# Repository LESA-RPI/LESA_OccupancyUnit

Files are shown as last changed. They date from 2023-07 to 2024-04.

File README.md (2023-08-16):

# LESA_OccupancyUnit (BLE_MeshLightingPRFNode)
## Tutorials
https://drive.google.com/drive/folders/18Ncf5kQ7dq59xiIikijq2Gq61cseJHMG?usp=sharing

## Table of Contents
- [Folder Navigation](#folder-navigation)
- [Flow charts](#flow-charts)
- [How to use](#how-to-use)
- [How it works](#how-it-works)
- [How it runs](#how-it-runs)
- [Bluetooth setting](#bluetooth-setting)
- [Tracking Algorithm](#tracking-algorithm)
- [Sensor related files](#sensor-related-files)
- [Summer Team Contact Information](#summer-team-contact-information)

## Folder Navigation
1. [NON-STM32 Project Folder](https://github.com/IAmiku/LESA_OccupancyUnit/tree/main/NON-STM32%20Project%20Folder)
    - [App](https://github.com/IAmiku/LESA_OccupancyUnit/tree/main/NON-STM32%20Project%20Folder/App)
    - [DataBase](https://github.com/IAmiku/LESA_OccupancyUnit/tree/main/NON-STM32%20Project%20Folder/DataBase)
    - [ESP-TCS3430](https://github.com/IAmiku/LESA_OccupancyUnit/tree/main/NON-STM32%20Project%20Folder/ESP-TCS3430)
    - [ESP-TMD3725/readreg](https://github.com/IAmiku/LESA_OccupancyUnit/tree/main/NON-STM32%20Project%20Folder/ESP-TMD3725/readreg)
    - [ESPreceverArduino](https://github.com/IAmiku/LESA_OccupancyUnit/tree/main/NON-STM32%20Project%20Folder/ESPreceverArduino)
2. [STM32CubeIDE](https://github.com/IAmiku/LESA_OccupancyUnit/tree/main/STM32CubeIDE)

Based on STM's *BLE_MeshLightingPRFNode* example, this project gets data from the ToF and color sensor. Bluetooth functionality has not been fully developed

## Flow charts

### Current Program Overview (STM32 occupancy detection)
```mermaid
graph TD
boot(Initilizaiton of STM32 and task registrations) ---> init(Sensor Init) --wait for init to finish--> standby{Standby};
subgraph Appli_mesh.c & others
standby --sw1 short press--> reply1(BLE color value advertisement);
reply1-->standby
standby --sw1 long press--> reply2(BLE ToF value advertisement);
reply2---> standby
standby --sw2 long press--> base(background set up)---> standby
standby -->change{Color INT}-->sensor(wakes up ToF and data pulling)--No blobs present for long period-->standby
standby --sw2 short press--> loopyloop1(ToF matrix to UART)
loopyloop1--sw2 short press--> standby
end
```

### Project Overview 
```mermaid
graph LR
subgraph Room
unit1[Server];unit2[Server];unit3[Server];unit4[Server];unit5{Client};
unit1 & unit2 ---- unit3 & unit4
unit5 ---- unit1
end
unit5 ---- building[Building management sys]
```
Server and Clients are defined by
```
#define ENABLE_SENSOR_MODEL_SERVER                                           (1)
#define ENABLE_SENSOR_MODEL_CLIENT                                           (0)
```
, where server is the one with sensor running, and client is the one requesting or listening

### Conituous ToF matrix pulling configuration
```mermaid
graph TD

server[Server]
esp[EPS32]
server <--HTTP--> esp
subgraph Module
stm[STM32] <--UART--> esp
stm <--I2C--> colorsensor[ColorS]
stm <--I2C--> tof[ToF]
end
```

## Wiring Diagram
<p align="center">
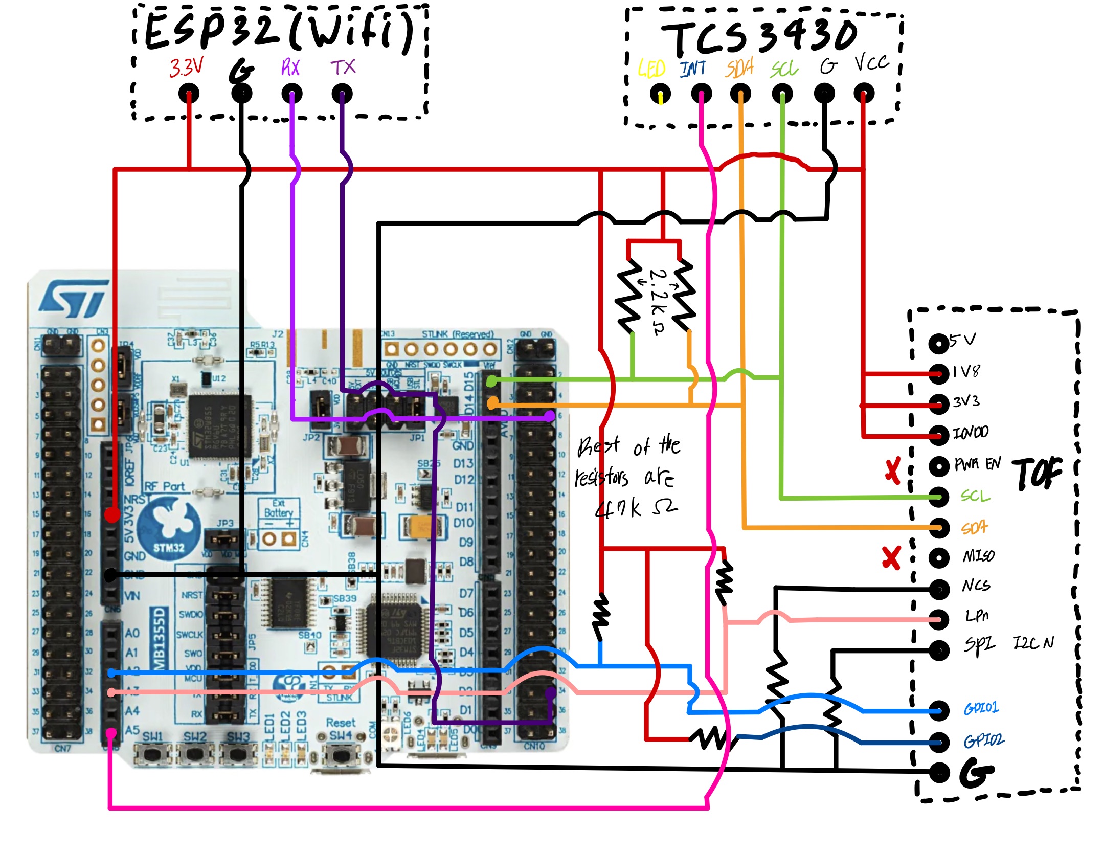
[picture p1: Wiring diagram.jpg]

</p>
Some of external resistors are necessary as the diagram above shown since the L8 TOF board does not internal resistors on it.

## How to use
In order to use this project you must download this entire repository and open the `.project` file in the STM32CubeIDE folder:

|  |  |
|--|--|
| This is how the files should be placed in the workspace folder | Open the project by clicking the .project file |

## How it works

### How it runs

The example software provided by ST uses a sequencer library for scheduling tasks. 

Before using the sequencer it must be initialized by a call to the function :

`UTIL_SEQ_Init( void )`

A function is registered as a task in the sequencer by

`UTIL_SEQ_RegTask( UTIL_SEQ_bm_t TaskId_bm, uint32_t Flags, void (*Task)( void ) )`

The first parameter is the task ID and is a 32-bit value where only one bit should be set, i.e. 
the maximum number of tasks is 32. The second parameter is not used for anything by the library, and the third parameter is a pointer to the function which should be called when it is time for the task to run.

To request a task to be runned, use function 

`UTIL_SEQ_SetTask( UTIL_SEQ_bm_t TaskId_bm , uint32_t Task_Prio )`

Example:
```
UTIL_SEQ_Init( void )
UTIL_SEQ_RegTask((1 << 4), UTIL_SEQ_RFU, my_task_function);
UTIL_SEQ_SetTask((1 << 4), CFG_SEQ_Prio_0);
```

### Bluetooth setting

This project envisioned using BLE mesh to communicate between units. Click [here](Doc/readme.txt) to learn more.

## Tracking Algorithm

[`Tracking_Algo.h`](Core/Inc/Tracking_Algo.h) Function declerations and Macro settings for STM32

[`Tracking_Algo.c`](Core/Src/Tracking_Algo.c) Algorithm itself, can be copied into an online C compiler to run and test

##### TODO: 
- update `void link_latest_frame_to_previous(FIFObuffer *fifobuffer)` to allow multi-frame traceback 
- update `void int find_centers_of_mass(int matrix[N][N], Point *center_of_mass)` in `FrameInfo parse_frame(int matrix[N][N], float deltaX, float deltaY)` to allow track person better

## Sensor related files

##### VL53L8CX (TOF Sensor)

    app_tof.c  ->  /BLE_MeshLightingPRFNode/Application/Core/app_tof.c

    - void MX_TOF_Init(void)
  
      : Initialize the TOF sensor. Validates whether it is properly connected and starts the sensor
  
    - static void MX_VL53L8CX_SimpleRanging_Process(void)
  
      : Read and print out the data if the sensor is properly running
  
    - void MX_TOF_ToggleReso(void)
  
      : A public function that calls toggle_resolution. Change the resolution of TOF sensor
  
    You can change the ranging frequency by modifying "RANGING_FREQUENCY" public variable(Set to 20Hz in the code)

    *custom_ranging_sensor.c  ->  /BLE_MeshLightingPRFNode/Application/Core/custom_ranging_sensor.c

    - int32_t CUSTOM_RANGING_SENSOR_Start(uint32_t Instance, uint8_t Mode)
  
      : Start the TOF sensor
  
    - int32_t CUSTOM_RANGING_SENSOR_Stop(uint32_t Instance)
  
      : Stop the TOF sensor

##### TCS3430 (Tristimulus Sensor)
https://github.com/IAmiku/LESA_OccupancyUnit/tree/main/NON-STM32%20Project%20Folder/ESP-TCS3430

    TCS3430.h  ->  /BLE_MeshLightingPRFNode/Drivers/BSP/TCS3430/TCS3430.h
 
    - Includes all the address of the registers of TCS3430
    
    - Includes Prototype of functions

    - struct tcs3430_optics_val

        : Has X,Y,Z, and IR values

    - struct tcs3430

        reginfo -> data in the registers

        XYZinfo -> Low & High byte of X, Y, Z, and IR1

    TCS3430.c  ->  /BLE_MeshLightingPRFNode/Drivers/BSP/TCS3430/TCS3430.c

    ............

Above two functions are necessary whenever you change the setting of the TOF(such as frequency of configure mode)

Reference:

https://wiki.st.com/stm32mcu/wiki/Connectivity:STM32WB_BLE_MESH_Sensor_Model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

### Summer Team Contact Information

•	link10@rpi.edu 

•	kims29@rpi.edu 

•	zhengj8@rpi.edu

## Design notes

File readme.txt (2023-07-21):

/**
  @page BLE_MeshLightingPRFNode application
  
  @verbatim
  ******************** (C) COPYRIGHT 2020 STMicroelectronics *******************
  * @file    BLE/BLE_MeshLightingPRFNode/readme.txt 
  * @author  MCD Application Team
  * @brief   Description of the BLE Mesh Lighting Proxy Relay Friend Node demo application.
  ******************************************************************************
  *
  * Copyright (c) 2019-2022 STMicroelectronics.
  * All rights reserved.
  *
  * This software is licensed under terms that can be found in the LICENSE file
  * in the root directory of this software component.
  * If no LICENSE file comes with this software, it is provided AS-IS.
  *
  ******************************************************************************
  @endverbatim

@par application Description 
This is the implementation of the BLE Mesh Lighting profile as specified by the BLE SIG,
a Proxy-Relay-Friend Node with the capacity to handle a Friendship with a Low Power Node.

@note Care must be taken when using HAL_Delay(), this function provides accurate delay (in milliseconds)
      based on variable incremented in SysTick ISR. This implies that if HAL_Delay() is called from
      a peripheral ISR process, then the SysTick interrupt must have higher priority (numerically lower)
      than the peripheral interrupt. Otherwise the caller ISR process will be blocked.
      To change the SysTick interrupt priority you have to use HAL_NVIC_SetPriority() function.
      
@note The application needs to ensure that the SysTick time base is always set to 1 millisecond
      to have correct HAL operation.

@par Keywords

Connectivity, BLE, IPCC, HSEM, RTC, UART, PWR, BLE protocol, BLE mesh, BLE pairing, BLE profile, Dual core

@par Directory contents
  - BLE_MeshLightingPRFNode/Core/Inc/app_common.h                  App Common application configuration file for STM32WPAN Middleware.
  - BLE_MeshLightingPRFNode/Core/Inc/app_conf.h                    Application configuration file for STM32WPAN Middleware.
  - BLE_MeshLightingPRFNode/Core/Inc/app_debug.h                   Header for app_debug.c module
  - BLE_MeshLightingPRFNode/Core/Inc/app_entry.h                   Interface to the application
  - BLE_MeshLightingPRFNode/Core/Inc/flash_driver.h                Dual core Flash driver interface
  - BLE_MeshLightingPRFNode/Core/Inc/hw_conf.h                     Configuration of hardware interface
  - BLE_MeshLightingPRFNode/Core/Inc/hw_if.h                       Hardware Interface
  - BLE_MeshLightingPRFNode/Core/Inc/lp_timer.h                    Header for lp_timer.c module
  - BLE_MeshLightingPRFNode/Core/Inc/main.h                        Header for main.c module
  - BLE_MeshLightingPRFNode/Core/Inc/stm32wbxx_hal_conf.h          HAL configuration file.
  - BLE_MeshLightingPRFNode/Core/Inc/stm32wbxx_it.h                This file contains the headers of the interrupt handlers.
  - BLE_MeshLightingPRFNode/Core/Inc/stm32_lpm_if.h                Header for stm32_lpm_if.c module (device specific LP management)
  - BLE_MeshLightingPRFNode/Core/Inc/utilities_conf.h              Configuration file for STM32 Utilities.
  - BLE_MeshLightingPRFNode/Core/Inc/vcp_conf.h                    Configuration of the vcp interface
  - BLE_MeshLightingPRFNode/STM32_WPAN/app/appli_config.h          Header file for the application config file 
  - BLE_MeshLightingPRFNode/STM32_WPAN/app/appli_config_client.h   Application interface for Generic Mesh Models  
  - BLE_MeshLightingPRFNode/STM32_WPAN/app/appli_generic.h         Application interface for Generic Mesh Models  
  - BLE_MeshLightingPRFNode/STM32_WPAN/app/appli_generic_client.h  Application interface for Generic Mesh Models  
  - BLE_MeshLightingPRFNode/STM32_WPAN/app/appli_light.h           Application interface for Light Mesh Model
  - BLE_MeshLightingPRFNode/STM32_WPAN/app/appli_light_client.h    Application interface for Generic Mesh Models  
  - BLE_MeshLightingPRFNode/STM32_WPAN/app/appli_light_lc.h        Application interface for Light Control Mesh Models  
  - BLE_MeshLightingPRFNode/STM32_WPAN/app/appli_mesh.h            Header file for the user application file 
  - BLE_MeshLightingPRFNode/STM32_WPAN/app/appli_nvm.h             Header file for the NVM application file 
  - BLE_MeshLightingPRFNode/STM32_WPAN/app/appli_sensor.h          Application interface for Light Mesh Model
  - BLE_MeshLightingPRFNode/STM32_WPAN/app/appli_sensors_client.h  Application interface for Sensor Mesh Models  
  - BLE_MeshLightingPRFNode/STM32_WPAN/app/appli_vendor.h          Application interface for Vendor Mesh Models  
  - BLE_MeshLightingPRFNode/STM32_WPAN/app/app_ble.h               Header for ble application
  - BLE_MeshLightingPRFNode/STM32_WPAN/app/ble_conf.h              Configuration file for BLE Middleware.
  - BLE_MeshLightingPRFNode/STM32_WPAN/app/ble_dbg_conf.h          Debug configuration file for BLE Middleware.
  - BLE_MeshLightingPRFNode/STM32_WPAN/app/hal_common.h            Common functions of HAL file 
  - BLE_MeshLightingPRFNode/STM32_WPAN/app/mesh_cfg_usr.h          user configurable settings 
  - BLE_MeshLightingPRFNode/STM32_WPAN/app/models_if.h             Mesh Modes interface file header 
  - BLE_MeshLightingPRFNode/STM32_WPAN/app/PWM_config.h            Header Configuration file for PWM.
  - BLE_MeshLightingPRFNode/STM32_WPAN/app/PWM_handlers.h          Header Handlers for PWM and other support functions.
  - BLE_MeshLightingPRFNode/STM32_WPAN/app/sensor_cfg_usr.h        sensor server initialization parameters 
  - BLE_MeshLightingPRFNode/STM32_WPAN/app/tl_conf.h               Transport Layer Configuration
  - BLE_MeshLightingPRFNode/STM32_WPAN/app/tl_dbg_conf.h           Debug configuration file for stm32wpan transport layer interface.
  - BLE_MeshLightingPRFNode/STM32_WPAN/app/user_if.h               Header file for User interface file 
  - BLE_MeshLightingPRFNode/STM32_WPAN/app/vcp_conf.h              Configuration of the vcp interface
  - BLE_MeshLightingPRFNode/Core/Src/app_debug.c                   Debug capabilities source file for STM32WPAN Middleware
  - BLE_MeshLightingPRFNode/Core/Src/app_entry.c                   Entry point of the Application
  - BLE_MeshLightingPRFNode/Core/Src/flash_driver.c                Dual core Flash driver interface
  - BLE_MeshLightingPRFNode/Core/Src/hw_timerserver.c              Hardware timerserver source file for STM32WPAN Middleware.
  - BLE_MeshLightingPRFNode/Core/Src/hw_uart.c                     HW UART source file for STM32WPAN Middleware.
  - BLE_MeshLightingPRFNode/Core/Src/lp_timer.c                    Low power timer to be used within Mesh Application.
  - BLE_MeshLightingPRFNode/Core/Src/main.c                        BLE application with BLE core
  - BLE_MeshLightingPRFNode/Core/Src/stm32wbxx_hal_msp.c           This file provides code for the MSP Initialization 
                                                                   and de-Initialization codes.
  - BLE_MeshLightingPRFNode/Core/Src/stm32wbxx_it.c                Main Interrupt Service Routines.
                                                                   This file provides template for all exceptions handler and
                                                                   peripherals interrupt service routine.
  - BLE_MeshLightingPRFNode/Core/Src/stm32_lpm_if.c                Low layer function to enter/exit low power modes (stop, sleep).
  - BLE_MeshLightingPRFNode/Core/Src/system_stm32wbxx.c            CMSIS Cortex Device Peripheral Access Layer System Source File
  - BLE_MeshLightingPRFNode/STM32_WPAN/app/appli_config.c          Config Model APIs callback from ST BLE Mesh Library
  - BLE_MeshLightingPRFNode/STM32_WPAN/app/appli_config_client.c   Application interface for Config CLient Mesh Model
  - BLE_MeshLightingPRFNode/STM32_WPAN/app/appli_generic.c         Application interface for Generic Mesh Models 
  - BLE_MeshLightingPRFNode/STM32_WPAN/app/appli_generic_client.c  Application interface for Generic Mesh Models 
  - BLE_MeshLightingPRFNode/STM32_WPAN/app/appli_light.c           Application interface for Lighting Mesh Models 
  - BLE_MeshLightingPRFNode/STM32_WPAN/app/appli_light_client.c    Application interface for Generic Mesh Models 
  - BLE_MeshLightingPRFNode/STM32_WPAN/app/appli_light_lc.c        Application interface for light LC Mesh Models 
  - BLE_MeshLightingPRFNode/STM32_WPAN/app/appli_mesh.c            User Application file 
  - BLE_MeshLightingPRFNode/STM32_WPAN/app/appli_nvm.c             User Application file 
  - BLE_MeshLightingPRFNode/STM32_WPAN/app/appli_sensor.c          Application interface for Sensor Mesh Models 
  - BLE_MeshLightingPRFNode/STM32_WPAN/app/appli_sensors_client.c  Application interface for Generic Mesh Models 
  - BLE_MeshLightingPRFNode/STM32_WPAN/app/appli_vendor.c          Application interface for Vendor Mesh Models 
  - BLE_MeshLightingPRFNode/STM32_WPAN/app/app_ble.c               BLE Application
  - BLE_MeshLightingPRFNode/STM32_WPAN/app/models_if.c             Mesh Modes interface file of the application
  - BLE_MeshLightingPRFNode/STM32_WPAN/app/pal_nvm.c               Flash management for the Controller
  - BLE_MeshLightingPRFNode/STM32_WPAN/app/PWM_config.c            Configuration file for PWM.
  - BLE_MeshLightingPRFNode/STM32_WPAN/app/PWM_handlers.c          Handlers for PWM and other support functions.
  - BLE_MeshLightingPRFNode/STM32_WPAN/app/svcctl_conf.c           Configuration of the BLE service controller
  - BLE_MeshLightingPRFNode/STM32_WPAN/app/tl_if.c                 Transport layer interface to BLE
  - BLE_MeshLightingPRFNode/STM32_WPAN/app/user_if.c               User interface file 
  - BLE_MeshLightingPRFNode/STM32_WPAN/target/hw_ipcc.c            Hardware IPCC source file for STM32WPAN Middleware.
     
@par Hardware and Software environment

  - This application runs on STM32WB55xx devices.
  
  - This application has been tested with an STMicroelectronics P-NUCLEO-WB55
    board and can be easily tailored to any other supported device 
    and development board.

  - This application is by default configured to support low power mode ( No traces - No debugger )
    This can be modified in app_conf.h (CFG_LPM_SUPPORTED, CFG_DEBUG_BLE_TRACE, CFG_DEBUG_APP_TRACE)

  - SMPS can be used to obtain the best performance in power consumption.
    This feature depends on board components and its activation can be done through specific define (CFG_USE_SMPS)
    configurable in app_conf.h
    See AN5246 - Usage of STM32WB Series microcontrollers.

@par How to use it ? 

This application requires having the stm32wb5x_BLE_Stack_full_fw.bin binary flashed on the Wireless Coprocessor.
If it is not the case, you need to use STM32CubeProgrammer to load the appropriate binary.
All available binaries are located under /Projects/STM32_Copro_Wireless_Binaries directory.
Refer to /Projects/STM32_Copro_Wireless_Binaries/ReleaseNote.html for the detailed procedure to change the
Wireless Coprocessor binary or see following wiki for Hardware setup:
https://wiki.st.com/stm32mcu/wiki/Connectivity:STM32WB_BLE_Hardware_Setup

In order to make the program work, you must do the following:
 - Open your preferred toolchain 
 - Rebuild all files and flash the board with the executable file
 
For more details refer to the Application Note: 
  AN5292_STM32WB_How_to_build_BLE_Mesh_Application
  
@Introduction

The ST BLE-Mesh library supports all of the following features in a Mesh node:
1. Relay: to forward received network PDUs on advertising or GATT bearer, if the Proxy feature is enabled
2. Proxy: to forward received network PDUs between GATT and advertising bearers
3. Friend: can perform duties such as scanning for other associated nodes that are usually Low Power mode
4. Low Power: consumes much less power as the node usually does not perform any scanning
A typical BLE Mesh node radio should always be in scanning mode to avoid missing packets over the air, but this kind of
operation is not supported by many devices due to continuous energy requirements.
To enable low power operation, BLE Mesh Profile v1.0 defines the concept of Friendship.
In a Mesh network, a Low Power feature-enabled Mesh node (LPN) offloads its packet receiving (scanning) duty to an adjacent
Friend feature-enabled Mesh node (FN). The LPN is not always scanning and remains inactive (or sleeps) for most of its life
cycle, significantly reducing its energy requirements. Nodes running on batteries or energy harvesting techniques usually
support the Low Power feature.
Once connected to each other, the FN and LPN are considered friends and their connection is known as a Friendship. At least
one FN must be in the direct radio range of an LPN to establish Friendship.
  
@Configuration

Low Power Node
Low Power feature support is defined in mesh_cfg_usr.h by the predefinition of ENABLE_LOW_POWER_FEATURE.
Note: A Low Power feature-enabled node does not support any other feature: all the other features should be
undefined.

@Demo setup based on STM32WB55RG-Nucleo

General default setting defined in mesh_cfg_usr.h:
        ENABLE_GENERIC_MODEL_SERVER_ONOFF                                    (1) /* GENERIC SERVER ONOFF MODEL ON FIRST ELEMENT */
        ENABLE_GENERIC_MODEL_SERVER_LEVEL                                    (1) /* GENERIC SERVER LEVEL MODEL ON FIRST ELEMENT */
        ENABLE_GENERIC_MODEL_SERVER_POWER_ONOFF                              (1) /* GENERIC SERVER POWER ONOFF MODEL ON FIRST ELEMENT */
        ENABLE_GENERIC_MODEL_SERVER_POWER_ONOFF_SETUP                        (1) /* GENERIC SERVER POWER ONOFF SETUP MODEL ON FIRST ELEMENT */
        ENABLE_LIGHT_MODEL_SERVER_LIGHTNESS                                  (1) /* LIGHT LIGHTNESS SERVER MODEL ON FIRST ELEMENT */
        ENABLE_LIGHT_MODEL_SERVER_LIGHTNESS_SETUP                            (1) /* LIGHT LIGHTNESS SETUP SERVER MODEL ON FIRST ELEMENT */
        APPLICATION_NUMBER_OF_ELEMENTS                                         1 /* NUMBER OF ELEMENT SUPPORTED */ 
        APPLICATION_SIG_MODELS_MAX_COUNT                                       6 /* TOTAL NUMBER OF MODELS SUPPORTED */
        APPLICATION_VENDOR_MODELS_MAX_COUNT                                    1->0 /* TOTAL NIMBER OF VENDOR MODELS SUPPORTED */
        ENABLE_RELAY_FEATURE                                                     /* RELAY SUPPORT */
        ENABLE_PROXY_FEATURE                                                     /* PROXY SUPPORT FOR GATT CONNECTION */
        ENABLE_FRIEND_FEATURE                                                    /* FRIEND SUPPORT FOR FRIENDSHIP WITH LOW POWER NODE */
        ENABLE_PB_ADV                                                            /* Provisioning Bearer over advertising channels support */
        ENABLE_PB_GATT                                                           /* Provisioning Bearer over GATT proxy support */ 

The following demo based on STM32WB55RG-Nucleo has been set up using one board as a Friend node and two
boards as Low Power nodes.

Low Power Node setup (use the Low Power Node BLE_MeshLightingLPN project):
Step 1. Configure LPN parameters.
        Change only if required otherwise skip this step (use application parameters defined in mesh_cfg_usr.h)
	    LPN_RSSI_FACTOR_LEVEL             1
        LPN_RECIVE_WINDOW_FACTOR_LEVEL    1
        LPN_MINIMUM_QUEUE_SIZE_LOG        2
        LPN_RECEIVE_DELAY                 150 ms
        LPN_POLL_TIMEOUT                  2000 (*100 ms)
        LPN_RECEIVE_WINDOW_SIZE           55 ms
        LPN_SUBSCR_LIST_SIZE              2
        LPN_FRIEND_REQUEST_FREQUENCY      50 (*100 ms)
        LPN_FRIEND_POLL_FREQUENCY         25 (*100 ms)
        LPN_MINIMUM_RSSI                  -100
        LPN_NO_OF_RETRIES                 10
Step 2. Generate and flash binary in 2 boards (LPN1, LPN2)

Friend Node setup (use the Proxy Relay Friend Node BLE_MeshLightingPRFNode project):
Step 1. Generate and flash binary in a board (FN)
Step 2. Provision the 3 boards with the default parameters, using BLE-Mesh Android (https://play.google.com/store/apps/details?id=com.st.bluenrgmesh&hl=en) or 
        BLE-Mesh iOS (https://apps.apple.com/us/app/st-ble-mesh/id1348645067) smartphone application (subscribe and publish to default group)

Demo operation
After provisioning, it might take a few seconds for Friendship to be established between FN and LPNs.
In this demo, the FN establishes Friendship with LPN1 and LPN2, LPN2 is optional.
Any packet targeted to LPN1/LPN2 or to a group address subscribed by LPN1 or LPN2 is put in queue by the FN
that forwards packets to LPN1/LPN2 as soon as it receives a Friend Poll from the respective LPN.
The LPN is free to send packets (generate traffic) any time.

By pressing [SW1] button on the Friend Node:
1. FN publishes a LED ON command to the default group and the FN blue LED immediately turns on (when the
FN belongs to the default group).
2. FN forwards a LED ON command to the LPNs subscribed to the default group. As soon as the FN receives
poll from an LPN, it sends LED ON to the respective LPN.

                     FN              LPN1            LPN2
                     |                |               |
           SW1 PUSH->|                |               |
        Blue LED on->|                |               |
                     |<--Friend Poll--|               |
                     |                |               |
                     |-----LED on---->|<-Blue LED on  |
                     |                                |
                     |<----------Friend Poll----------|
                     |                                |
                     |-------------LED on------------>|<-Blue LED on
                     |                                |

By pressing [SW1] button on the Low Power Node 1:
1. LPN1 publishes an LED OFF command to the default group. LPN1 blue LED tunrs off. 
   LPN1 immediately forwards LED OFF command to the default group.
2. FN receives an LED OFF command (as it is subscribed to the default group) and the FN blue LED turns off.
3. FN also sends an LED OFF command to LPN2 (subscribed to the default group) as soon as FN receives
   poll from LPN2.

                     FN              LPN1            LPN2
                     |                |               |
                     |      SW1 PUSH->|<-Blue LED off |
       Blue LED off->|<----LED off----|               |
                     |                                |
                     |<----------Friend Poll----------|
                     |                                |
                     |------------LED off------------>|<-Blue LED off
                     |                                |

Available Wiki pages:
  - https://wiki.st.com/stm32mcu/wiki/Connectivity:BLE_overview
  - https://wiki.st.com/stm32mcu/wiki/Connectivity:BLE_MESH_overview
  - https://wiki.st.com/stm32mcu/wiki/Connectivity:BLE_MESH_LPN
  - https://wiki.st.com/stm32mcu/wiki/Connectivity:BLE_MESH_Lighting

For more details refer to the Application Note: 
  AN5289 - Building a Wireless application
  AN5292 - STM32WB How to build BLE Mesh Application
 
* <h3><center>&copy; COPYRIGHT STMicroelectronics</center></h3>
 */

 reference:
https://wiki.st.com/stm32mcu/wiki/Connectivity:STM32WB_BLE_MESH_Sensor_Model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

- BLE_MeshLightingPRFNode/STM32_WPAN/app/mesh_cfg_usr.h         User configurable settings 
 																Set sensor client/server in following
			 																
			#define ENABLE_SENSOR_MODEL_SERVER                                           (1)
			#define ENABLE_SENSOR_MODEL_CLIENT                                           (0)

- BLE_MeshLightingPRFNode/STM32_WPAN/app/appli_mesh.c           User Application file 
																Set button click actions

- BLE_MeshLightingPRFNode/STM32_WPAN/app/sensor_cfg_usr.h        sensor server initialization parameters  																
 
- BLE_MeshLightingPRFNode/STM32_WPAN/app/appli_sensor.c          Application interface for Sensor Mesh Models 
																Appli_Sensor_Init to initialize all the sensors
																Appli_Sensor_ReadValue to read the sensor data
																Sensor_Get to 

- BLE_MeshLightingPRFNode/Core/Src/stm32wbxx_nucleo_bus.c		I2C init
 
	ToF L8 files:
- BLE_MeshLightingPRFNode/Core/Src/app_tof.c
  BLE_MeshLightingPRFNode/Core/Inc/app_tof.h 					 High Level Api functions
  
- BLE_MeshLightingPRFNode/STM32CubeIDE/Drivers/BSP/vl53l8cx      Essential drivers stuff

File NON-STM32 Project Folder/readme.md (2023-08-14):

App - python based app to visualize data from serial

DataBase - server held php files to recieve requests

ESPreceverArduino - arduino code using esp to send data to server

ESP-TCS3430 - arduino code using esp to read from TCS

ESP-TMD3725 - arduino code using esp to read from TMD

K-Mean Clustering - Another way to detect blobs from data

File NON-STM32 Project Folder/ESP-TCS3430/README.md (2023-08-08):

This program is not important to the final project. This produces a spectrometer that lights up an led with a sensed color.

It uses two ESP32, one with color sensor attached and the other with neopixel (rgb LED). 

The color sensor ESP32 would send XYZ values to the other ESP32, which would try to replicate the same color on its neopixel LED.

After flashing both ESP32 with their python programs and powering both boards you end up with a spectrometer.

```mermaid
graph LR
esp1[ESP32]
esp2[ESP32 with neopixel]
cols[ColorSensor]
computer[PC with python running]
computer --flash--> esp1 & esp2
esp1<--ESP NOW-->esp2
esp1<--I2C-->cols
```

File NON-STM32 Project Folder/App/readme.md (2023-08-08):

comport.py - python app to read data from serial port and visualize data package (ToF, center of mass, velocity, direction, height). There is a major issue with the delay between the sensor and the app.

Sage_GUI (old) based app - python app based off previous team's app

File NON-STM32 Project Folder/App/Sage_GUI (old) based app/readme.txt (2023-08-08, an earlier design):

main.py - latest version of app based on SageGUI

GUI_tk_pil.py - base app file from Sage Lab project
App_Progress.docx - documentation on app progress
ToF+Cam.py - app to show camera and tof visualization (dummy data)
Animated_test.py - test app to figure out how to animate plots in tkinter
AnimatedSensors.py - app to show ToF and Color Sensor visualization (dummy data)
saveCSV- test app decern how to record data

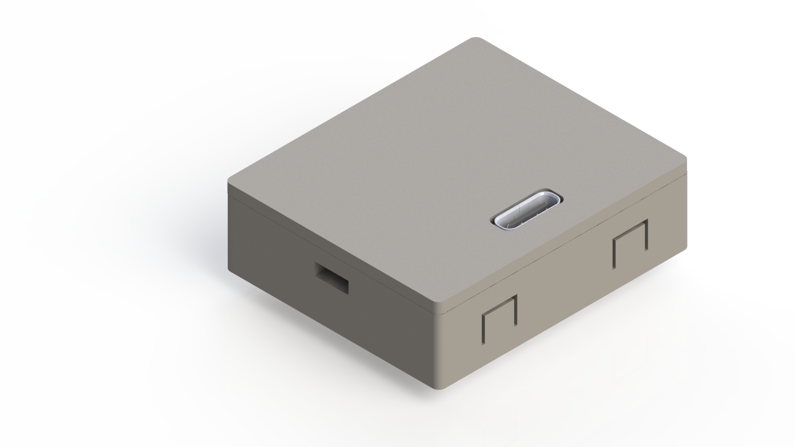
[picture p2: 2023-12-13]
Hardware/Enclosure/RenderImages/OSCASSY3.png

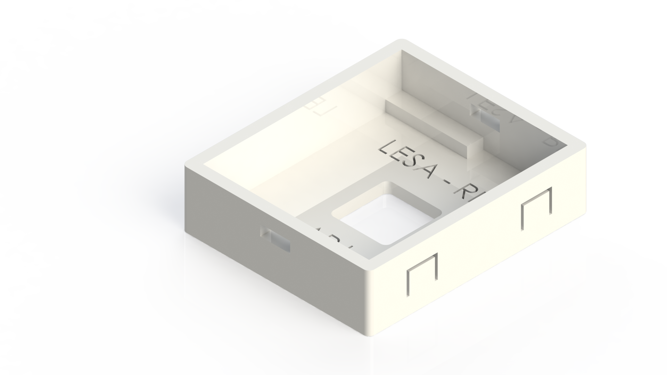
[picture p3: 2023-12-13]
Hardware/Enclosure/RenderImages/OSCB2.png

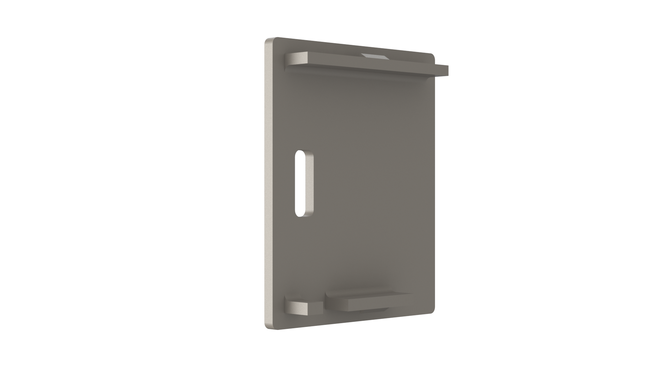
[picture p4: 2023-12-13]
Hardware/Enclosure/RenderImages/OSCB3view2.png

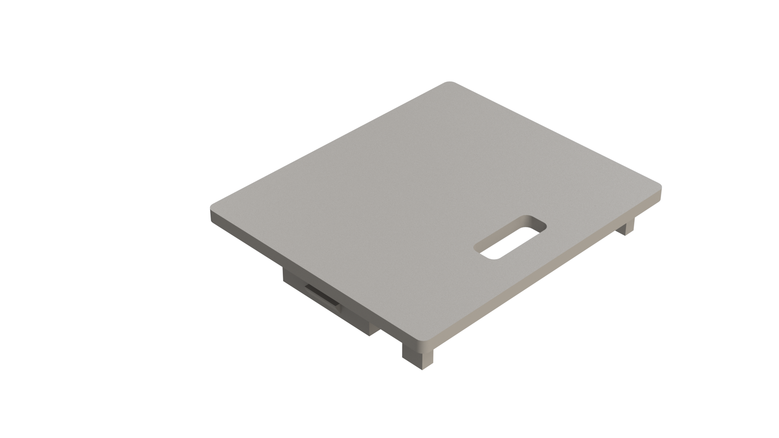
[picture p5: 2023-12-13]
Hardware/Enclosure/RenderImages/OSCB3-2.png

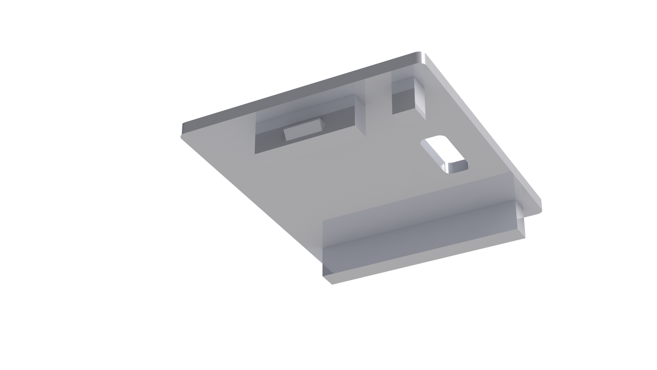
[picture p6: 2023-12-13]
Hardware/Enclosure/RenderImages/OSCB.png

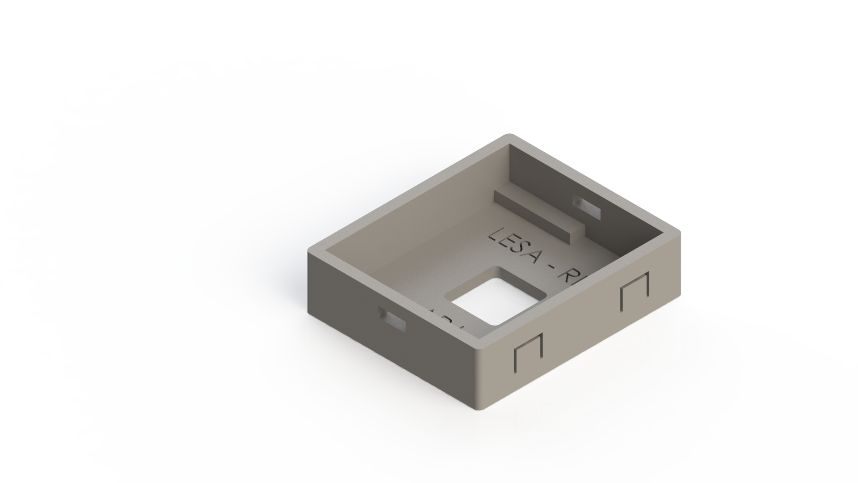
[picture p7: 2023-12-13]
Hardware/Enclosure/RenderImages/OSCB3.png

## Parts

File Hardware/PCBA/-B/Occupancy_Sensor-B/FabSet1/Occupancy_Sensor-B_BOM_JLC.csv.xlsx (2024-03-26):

Comment | Designator | Footprint | JLCPCB Part #
4.7u | C1,C13,C15,C19 | 0402 | C23733
100n | C2,C4,C9,C16,C17,C18,C20,C21,C22 | 0402 | C1525
1u | C3,C5,C6,C7,C8,C10 | 0402 | C52923
10n | C11,C26 | 0402 | C15195
10p | C12,C14 | 0402 | C32949
100p | C23 | 0402 | C1546
0.8p | C24 | 0402 | C327032
0.3p | C25 | 0402 | C610035
1.2p | C30 | 0402 | C327292
PWR | D1 | 0603 | C2286
STAT | D2 | 0603 | C72043
Conn_02x05_Odd_Even | J2 | PinHeader_2x05_P1.27mm_Vertical_SMD
Conn_Coaxial | J3 | CONUFL001-SMD-T
USB_C_Receptacle | J4 | USB4120-03-C
10u | L1 | 0805 | C98030
10n | L2 | 0402 | C3911026
2.7n | L3 | 0402 | C77108
0R | L4 | 0603 | C21189
3.6n | L5 | 0402 | C19216
BSS138 | Q1,Q2,Q3,Q4,Q7 | SOT-23 | C2938375
DMG1012T | Q6 | SOT-523 | C2830301
5.1K | R1,R2 | 0402 | C25905
47K | R3,R5,R6,R7,R9,R10,R12 | 0402 | C25792
40.2K | R4,R11 | 0402 | C25893
1K | R8,R13,R15,R21 | 0402 | C11702
2.2K | R14,R16,R17,R18,R19,R20 | 0402 | C25879
BOOT, RST | SW1,SW2 | EVQ-P7A01P
TPS7A0333PDBVR | U1 | SOT-23-5
VL53L8CX | U2 | VL53L8CX
ECMF02-2AMX6 | U3 | ST_UQFN-6L_1.5x1.7mm_P0.5mm | C2651144
TPS7A0318PDBVR | U4 | SOT-23-5
TCS3430 | U5 | TCS3430
STM32WB55CGUx | U6 | QFN-48-1EP_7x7mm_P0.5mm_EP5.6x5.6mm | C404023
DEA162450BT-1295A1 | U8 | DEA162450BT-1295A1 | C695579
NX2016SA_32M | Y2 | NX2016SA_32M | C1986260
NX2012_32K768 | Y3 | NX2012_32K768

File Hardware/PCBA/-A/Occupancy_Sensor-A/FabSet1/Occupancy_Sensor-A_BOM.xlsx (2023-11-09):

Designator | Value | Footprint | Digikey Link | Part # | Quantity
C1,C13,C15,C19 | 4.7u | 0402 | https://www.digikey.com/en/products/detail/samsung-electro-mechanics/CL05A475MP5NRNC/3887140 | CL05A475MP5NRNC | 4
C2,C4,C9,C16-C18,C20-C22 | 100n | 0402 | https://www.digikey.com/en/products/detail/samsung-electro-mechanics/CL05A104KA5NNNC/3886701 | CL05A104KA5NNNC | 9
C3,C5-C8,C10 | 1u | 0402 | https://www.digikey.com/en/products/detail/samsung-electro-mechanics/CL05A105KP5NNNC/3886734 | CL05A105KP5NNNC | 6
C11,C26 | 10n | 0402 | https://www.digikey.com/en/products/detail/samsung-electro-mechanics/CL05B103KB5NNNC/3886686 | CL05B103KB5NNNC | 2
C12,C14 | 10p | 0402 | https://www.digikey.com/en/products/detail/murata-electronics/GRM1555C1H100FA01D/2543854 | GRM1555C1H100FA01D | 2
C23 | 100p | 0402 | https://www.digikey.com/en/products/detail/murata-electronics/GRM1555C1H101JA01D/3693829 | GRM1555C1H101JA01D | 1
C24 | 0.8p | 0402 | https://www.digikey.com/en/products/detail/yageo/CC0402BRNPO9BNR80/5883200 | CC0402BRNPO9BNR80 | 1
C25 | 0.3p | 0402 | https://www.digikey.com/en/products/detail/murata-electronics/GRM1555C1HR30BA01J/4358110 | GRM1555C1HR30BA01J | 1
C30 | 1.2p | 0402 | https://www.digikey.com/en/products/detail/yageo/CC0402CRNPO9BN1R2/302736 | CC0402CRNPO9BN1R2 | 1
D1 | PWR | 0603 | https://www.digikey.com/en/products/detail/liteon/LTST-C191KRKT/386837 | LTST-C191KRKT | 1
D2 | STAT | 0603 | https://www.digikey.com/en/products/detail/liteon/LTST-C190GKT/269230 | LTST-C190GKT | 1
J2 | Conn_02x05_Odd_Even | PinHeader_2x05_P1.27mm_Vertical_SMD | https://www.digikey.com/en/products/detail/amphenol-cs-fci/20021121-00010C4LF/2209057 | 20021121-00010C4LF | 1
J3 | Conn_Coaxial | CONUFL001-SMD-T | https://www.digikey.com/en/products/detail/te-connectivity-linx/CONUFL001-SMD-T/7427732 | CONUFL001-SMD-T | 1
J4 | USB_C_Receptacle | USB4120-03-C | https://www.digikey.com/en/products/detail/gct/USB4115-03-C/13557449 | USB4115-03-C | 1
L1 | 10u | 0805 | https://www.digikey.com/en/products/detail/murata-electronics/LQM21FN100M70L/1016188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 | LQM21FN100M70L | 1
L2 | 10n | 0402 | https://www.digikey.com/en/products/detail/murata-electronics/LQG15WZ10NJ02D/6798669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 | LQG15WZ10NJ02D | 1
L3 | 2.7n | 0402 | https://www.digikey.com/en/products/detail/murata-electronics/LQG15HS2N7S02D/662864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 | LQG15HS2N7S02D | 1
L4 | 0R | 0603 | https://www.digikey.com/en/products/detail/bourns-inc/CR0603AJ-000EAS/10240122 | CR0603AJ/-000EAS | 1
L5 | 3.6n | 0402 | https://www.digikey.com/en/products/detail/murata-electronics/LQG15HS3N6S02D/2594221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 | LQG15HS3N6S02 | 1
Q1-Q4,Q7 | BSS138 | SOT-23 | https://www.digikey.com/en/products/detail/onsemi/BSS138/244210 | BSS138 | 5
Q6 | DMG1012T | SOT-523 | https://www.digikey.com/en/products/detail/diodes-incorporated/DMG1012T-7/2174582 | DMG1012T-7 | 1
R1,R2 | 5.1K | 0402 | https://www.digikey.com/en/products/detail/panasonic-electronic-components/ERJ-2RKF5101X/1746242 | ERJ-2RKF5101X | 2
R3,R5-R7,R9,R10,R12 | 47K | 0402 | https://www.digikey.com/en/products/detail/panasonic-electronic-components/ERJ-2RKF4702X/1746233 | ERJ-2RKF4702X | 7
R4,R11 | 40.2K | 0402 | https://www.digikey.com/en/products/detail/yageo/RC0402FR-1340K2L/16982167 | RC0402FR-1340K2L | 2
R8,R13,R15,R21 | 1K | 0402 | https://www.digikey.com/en/products/detail/panasonic-electronic-components/ERJ-2RKF1001X/79729 | ERJ-2RKF1001X | 4
R14,R16-R20 | 2.2K | 0402 | https://www.digikey.com/en/products/detail/panasonic-electronic-components/ERJ-2RKF2201X/1746150 | ERJ-2RKF2201X | 6
SW1, SW2 | BOOT, RST | EVQ-P7A01P | https://www.digikey.com/en/products/detail/panasonic-electronic-components/EVQ-P7A01P/4429447 | EVQ-P7A01P | 2
U1 | TPS7A0333PDBVR | SOT-23-5 | https://www.digikey.com/en/products/detail/texas-instruments/TPS7A0333PDBVR/12165108?gad_source=1 | TPS7A0333PDBVR | 1
U2 | VL53L8CX | VL53L8CX | https://www.digikey.com/en/products/detail/stmicroelectronics/VL53L8CXV0GC-1/18085238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 | VL53L8CXV0GC/1 | 1
U3 | ECMF02-2AMX6 | ST_UQFN-6L_1.5x1.7mm_P0.5mm | https://www.digikey.com/en/products/detail/stmicroelectronics/ECMF02-2AMX6/2440273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 | ECMF02-2AMX6 | 1
U4 | TPS7A0318PDBVR | SOT-23-5 | https://www.digikey.com/en/products/detail/texas-instruments/TPS7A0318PDBVR/12165165 | TPS7A0318PDBVR | 1
U5 | TCS3430 | TCS3430 | https://www.digikey.com/en/products/detail/ams-osram-usa-inc/TCS34303/7428283 | TCS34303 | 1
U6 | STM32WB55CGUx | QFN-48-1EP_7x7mm_P0.5mm_EP5.6x5.6mm | https://www.digikey.com/en/products/detail/stmicroelectronics/STM32WB55CGU6/9919554 | STM32WB55CGU6 | 1
U8 | DEA162450BT-1295A1 | DEA162450BT-1295A1 | https://www.digikey.com/en/products/detail/tdk-corporation/DEA162450BT-1295A1/8546672 | DEA162450BT-1295A1 | 1
Y2 | NX2016SA_32M | NX2016SA_32M | https://www.digikey.com/en/products/detail/ndk-america-inc/CS06465-32M/7645290 | CS06465-32M | 1
Y3 | NX2012_32K768 | NX2012_32K768 | https://www.digikey.com/en/products/detail/ndk-america-inc/NX2012SA-32-768KHZ-EXS00A-MU00797/9172013 | MU00797-32.768K | 1

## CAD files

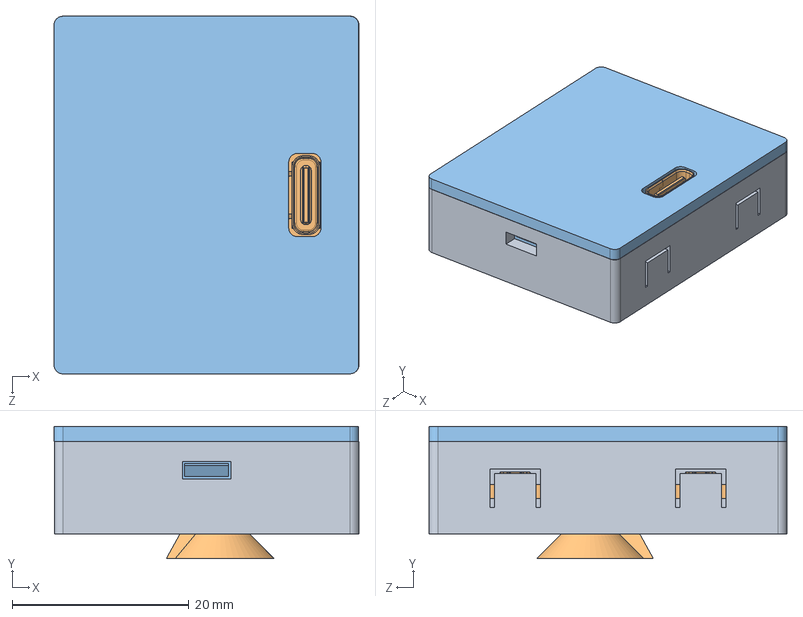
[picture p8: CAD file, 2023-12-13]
Hardware/Enclosure/Assys/Occupancy_Assy-A.SLDASM
34.5 x 15.0 x 40.5 mm
Occupancy_Sensor_Case_Top-A
Occupancy_Sensor-A
Occupancy_Sensor_Case_Bottom-A

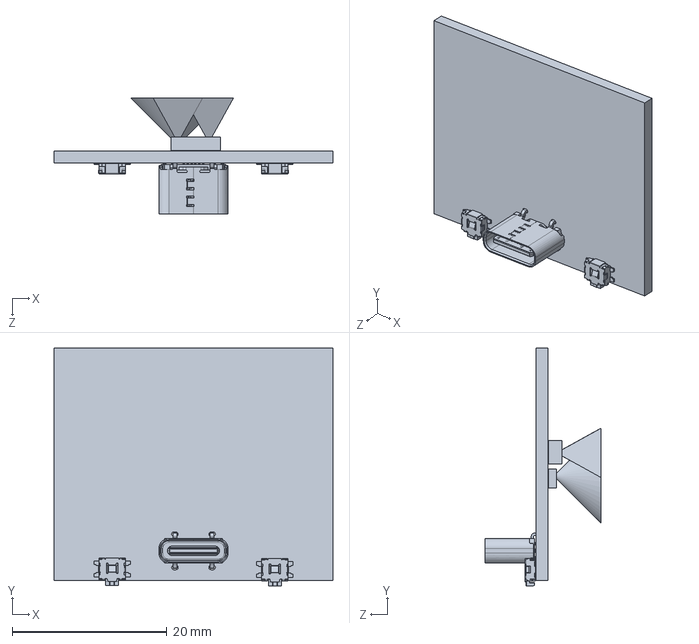
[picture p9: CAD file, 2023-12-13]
Hardware/Enclosure/Parts/Occupancy_Sensor-A.SLDPRT
36.0 x 30.7 x 14.9 mm

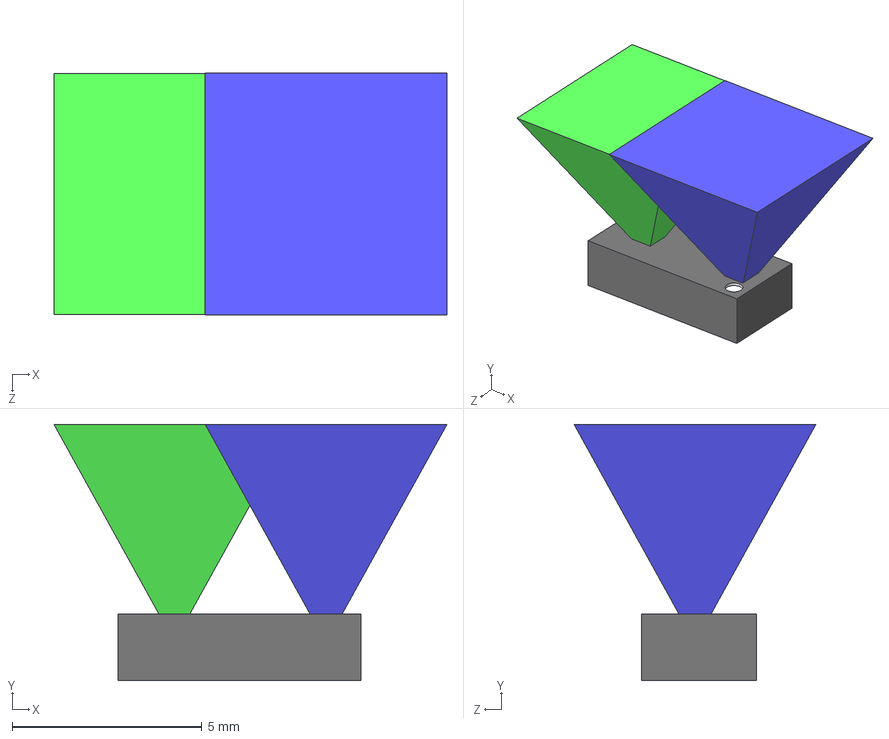
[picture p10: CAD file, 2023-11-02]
Hardware/ExclusionZoneModels/VL53L8CX_exclusion_r2.STEP
10.4 x 6.75 x 6.38 mm

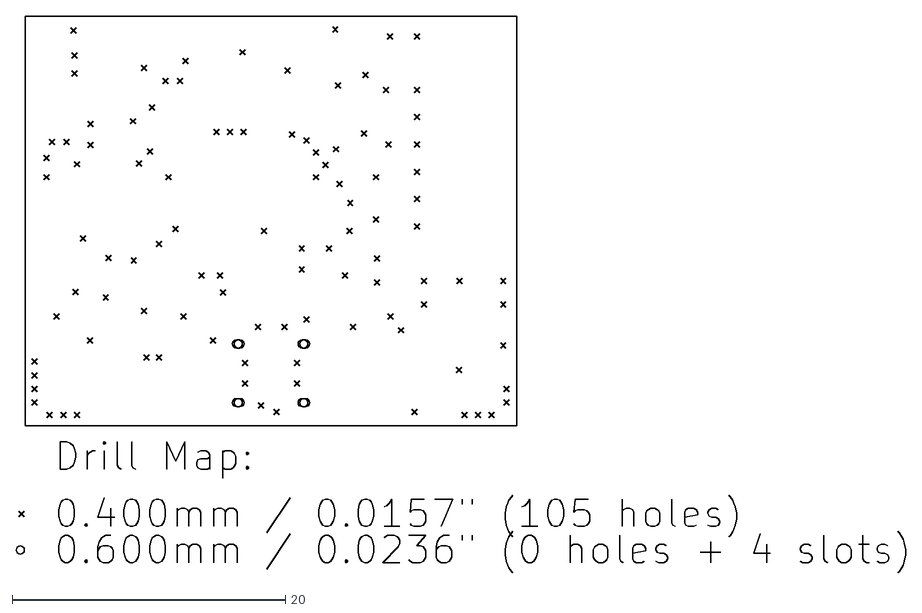
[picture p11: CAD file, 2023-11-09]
Hardware/PCBA/-A/Occupancy_Sensor-A/FabSet1/Occupancy_Sensor-A-PTH-drl_map.dxf
65.1 x 40.8

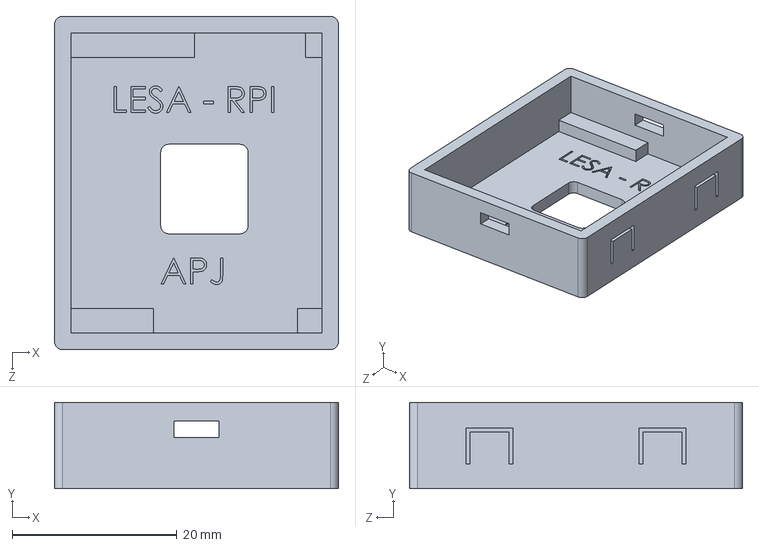
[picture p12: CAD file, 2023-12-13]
Hardware/Enclosure/Parts/Occupancy_Sensor_Case_Top-A.SLDPRT
34.5 x 10.4 x 40.5 mm

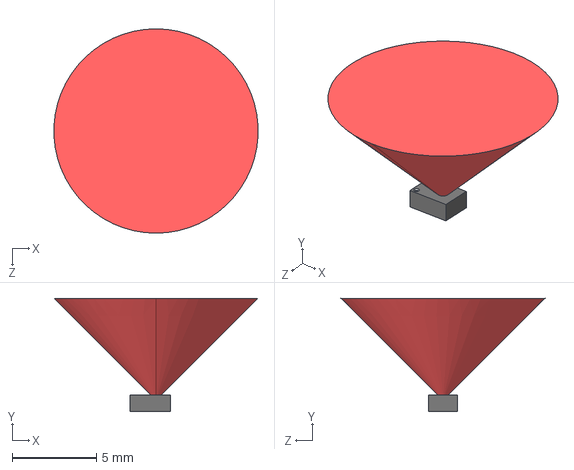
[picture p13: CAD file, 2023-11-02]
Hardware/ExclusionZoneModels/TCS3430_exclusion_r2.STEP
12.1 x 6.75 x 12.2 mm

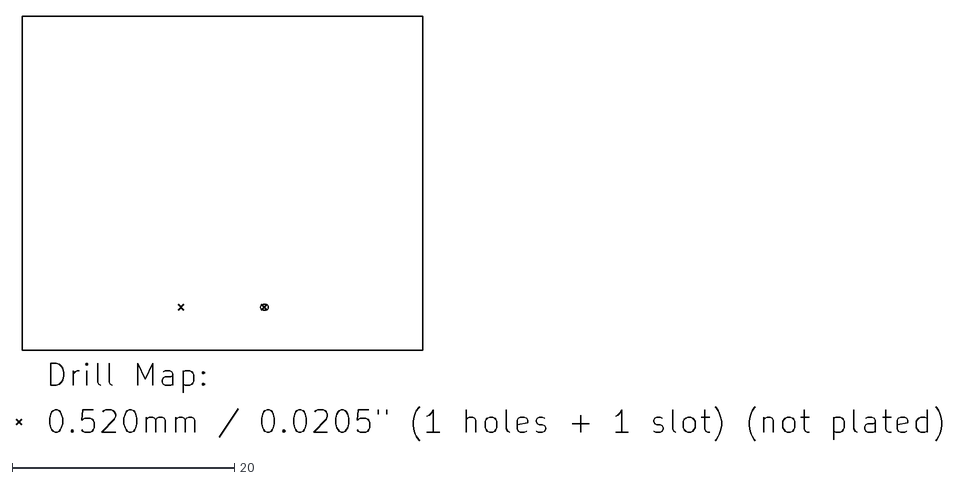
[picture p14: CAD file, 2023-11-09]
Hardware/PCBA/-A/Occupancy_Sensor-A/FabSet1/Occupancy_Sensor-A-NPTH-drl_map.dxf
83.2 x 38.1

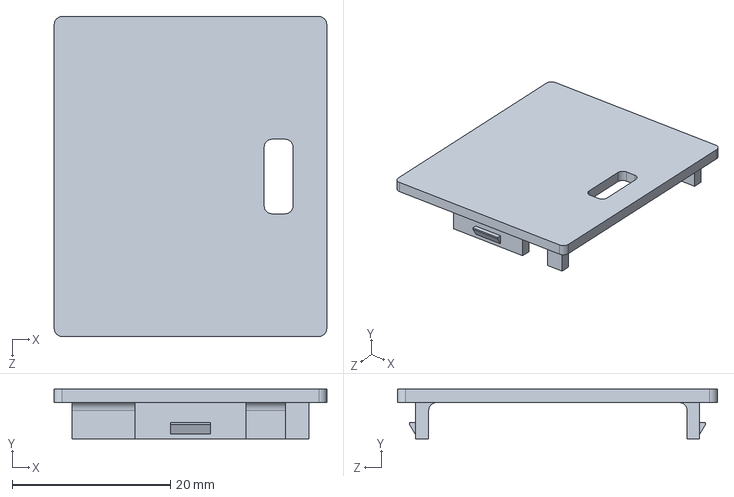
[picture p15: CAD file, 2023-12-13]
Hardware/Enclosure/Parts/Occupancy_Sensor_Case_Bottom-A.SLDPRT
34.5 x 6.30 x 40.5 mm

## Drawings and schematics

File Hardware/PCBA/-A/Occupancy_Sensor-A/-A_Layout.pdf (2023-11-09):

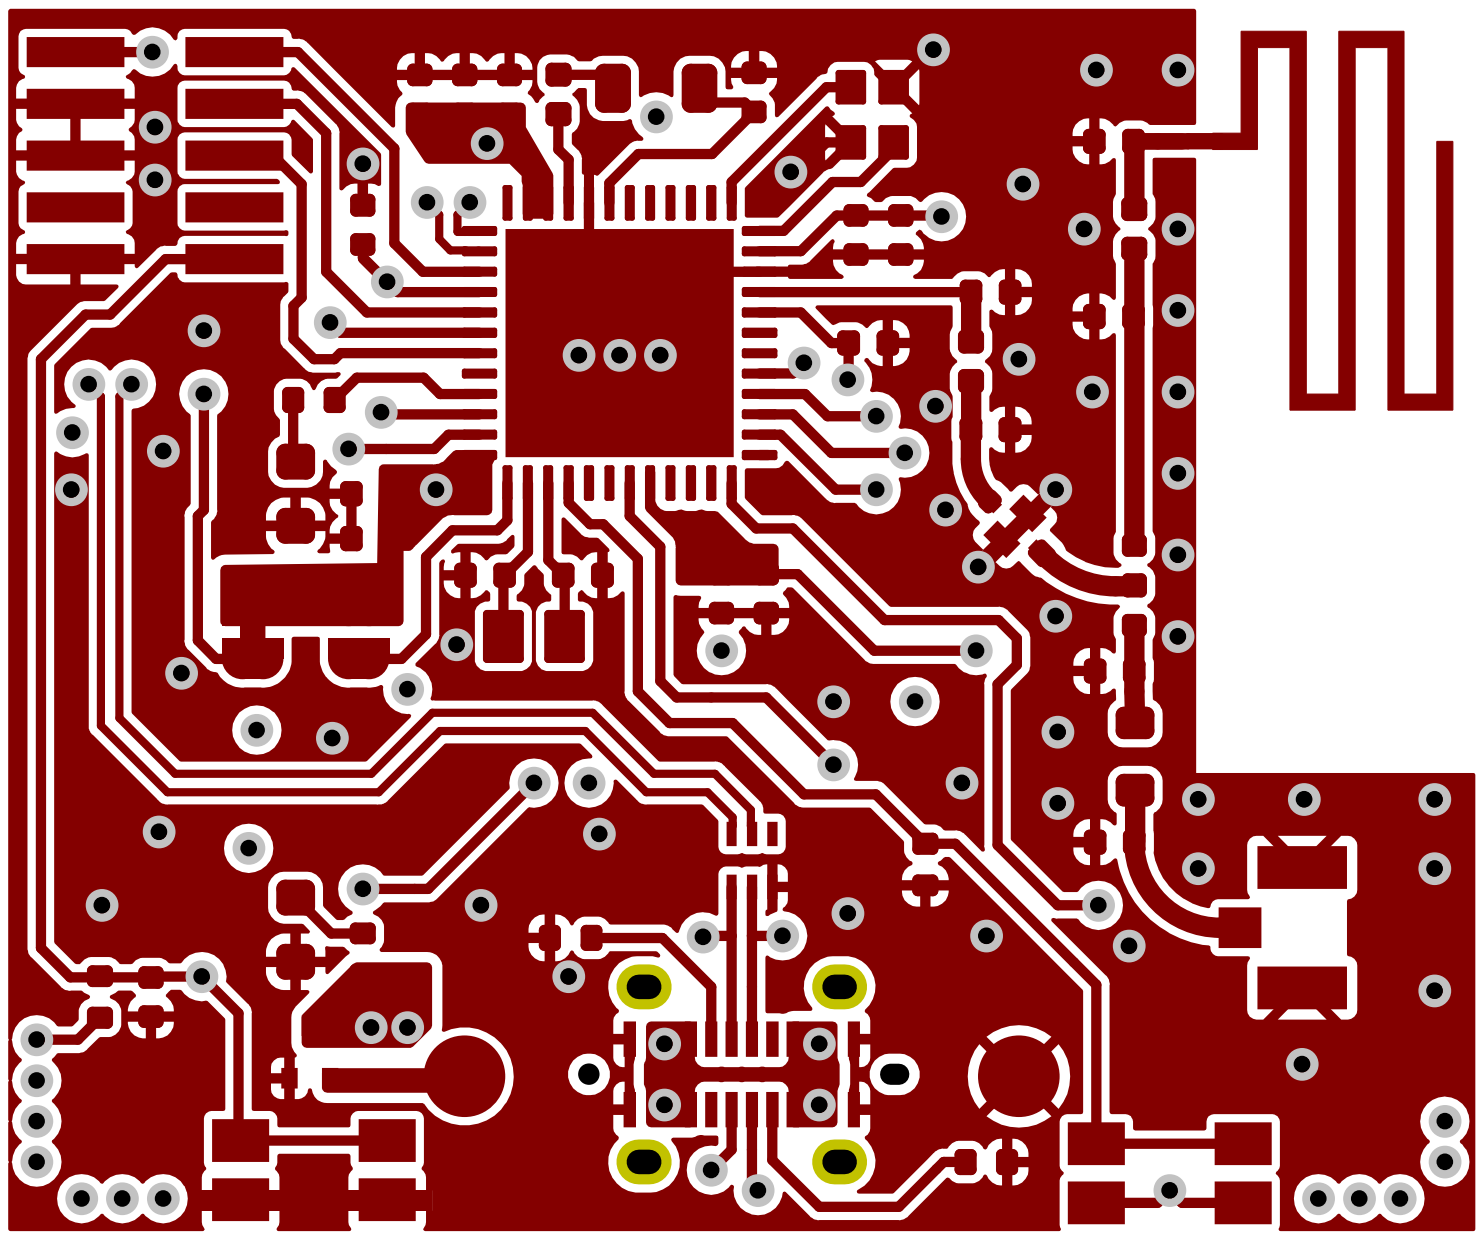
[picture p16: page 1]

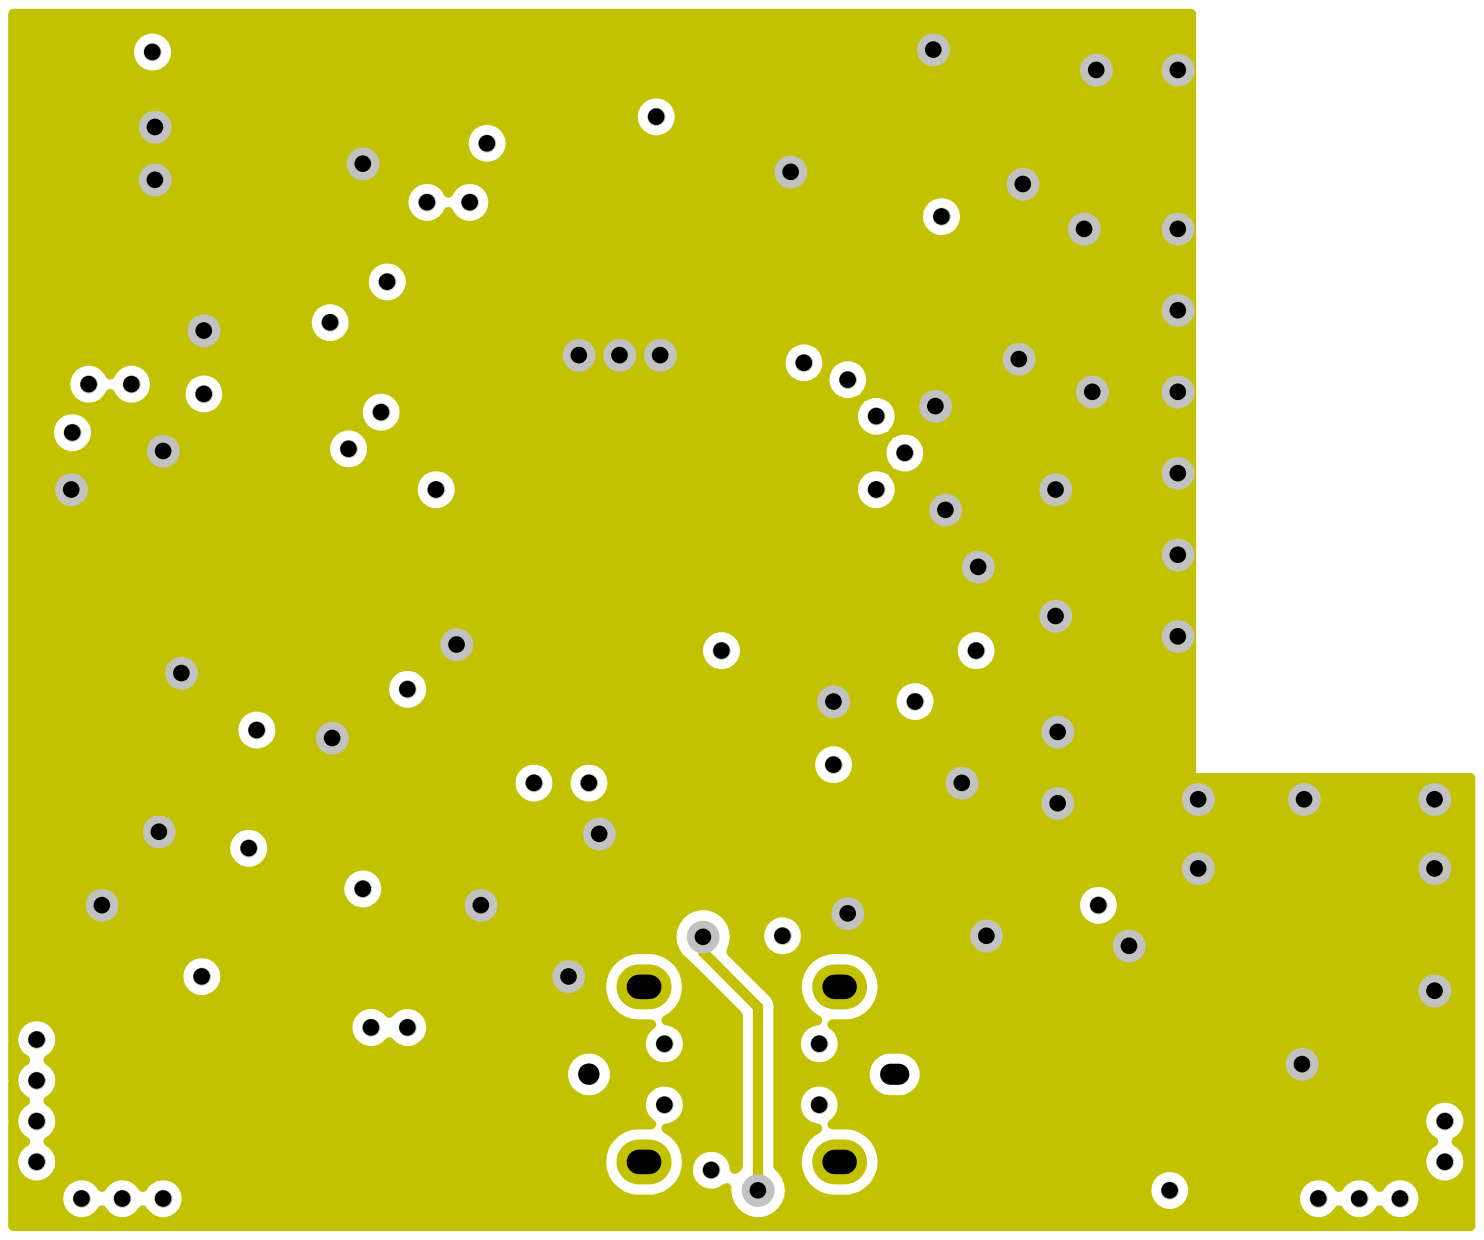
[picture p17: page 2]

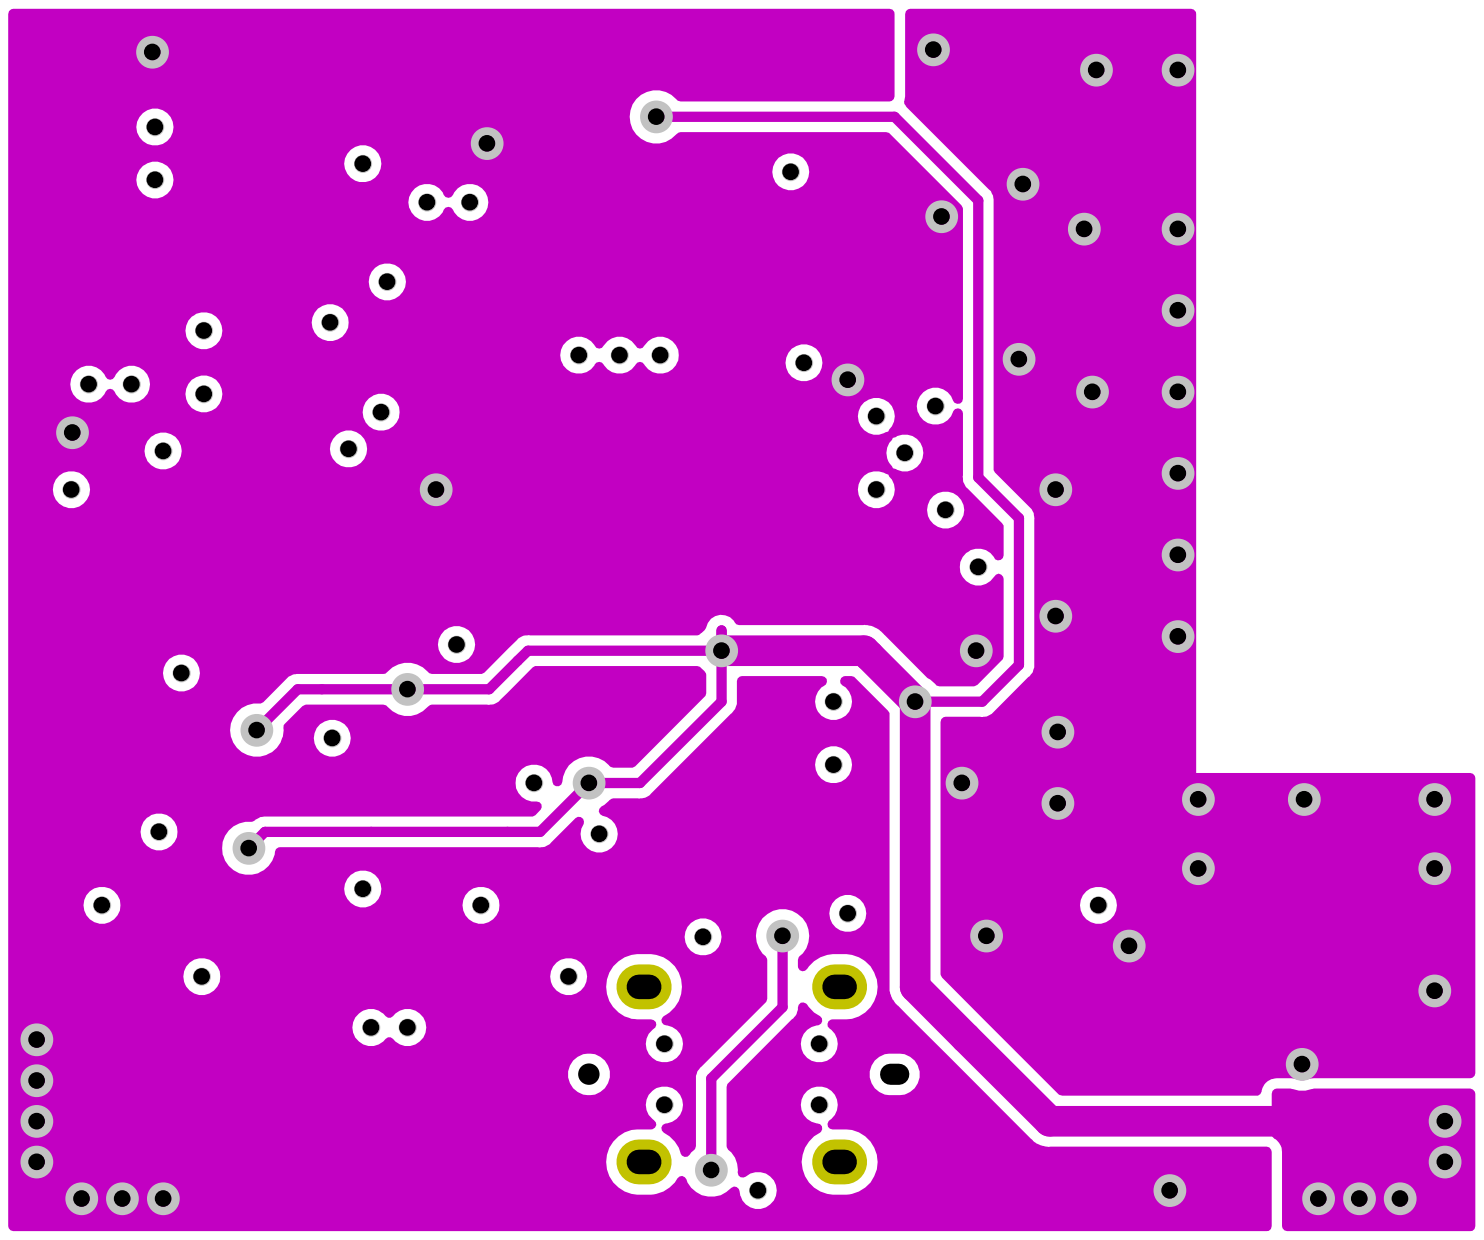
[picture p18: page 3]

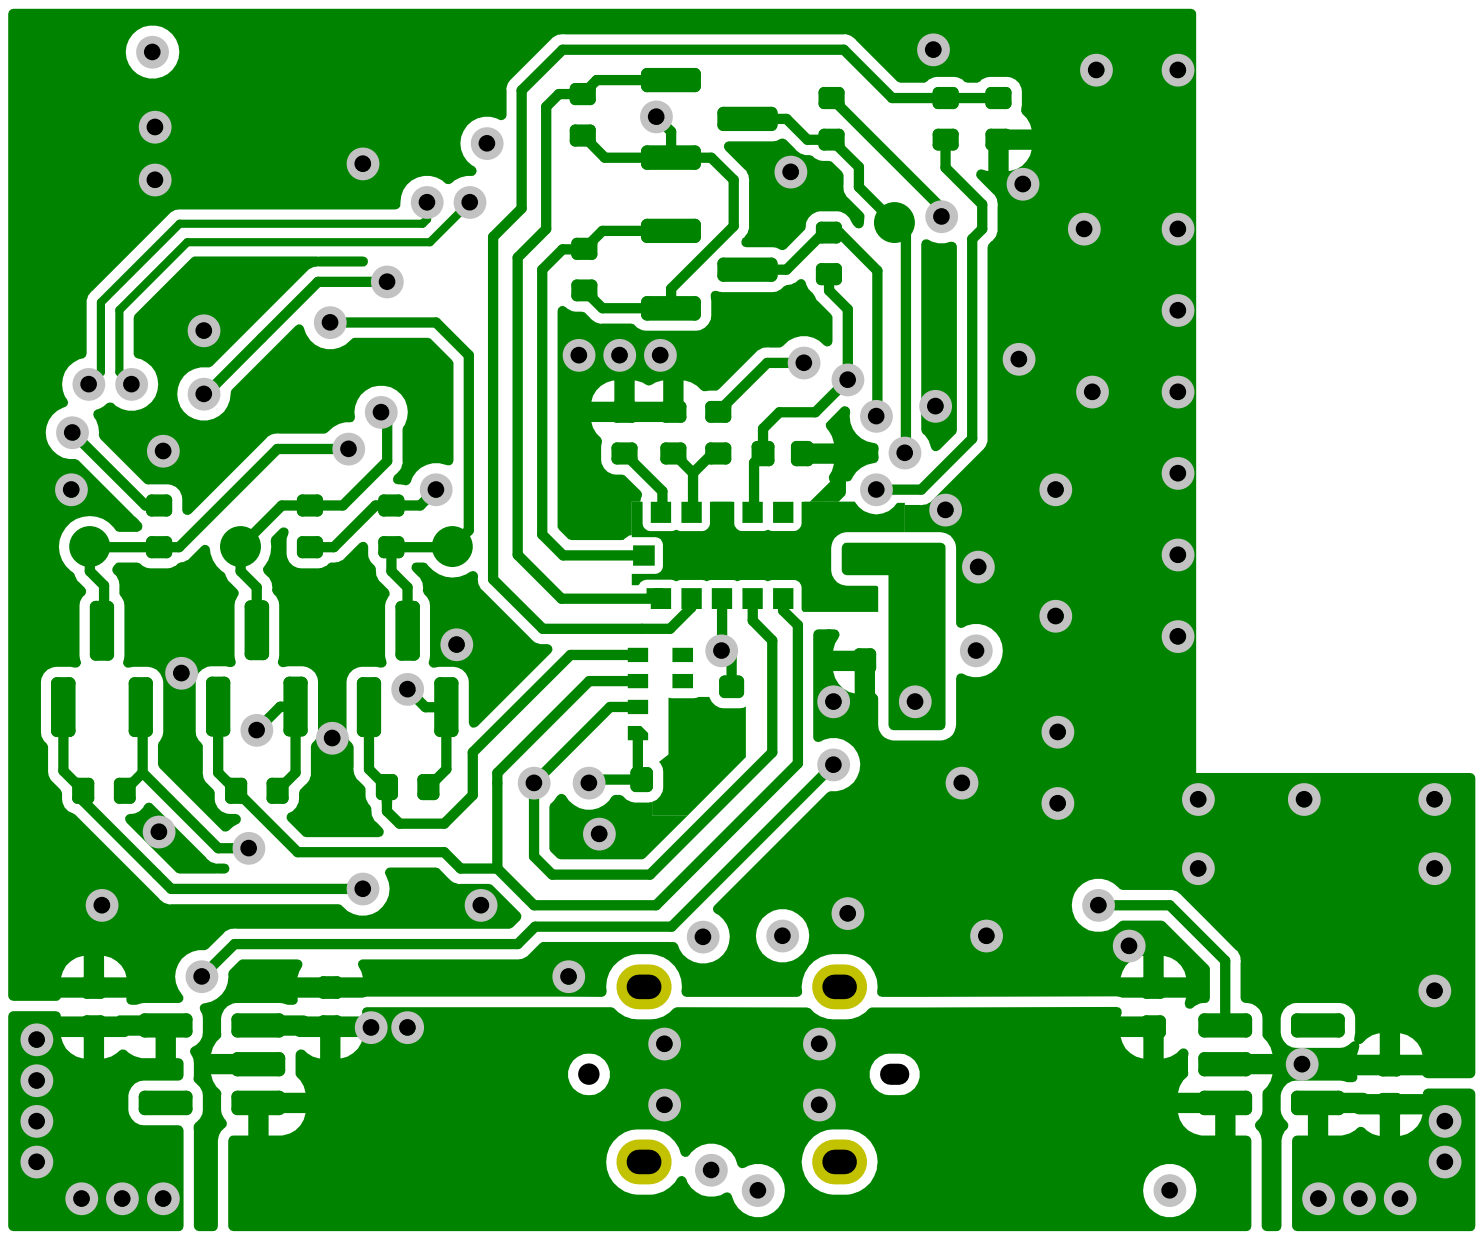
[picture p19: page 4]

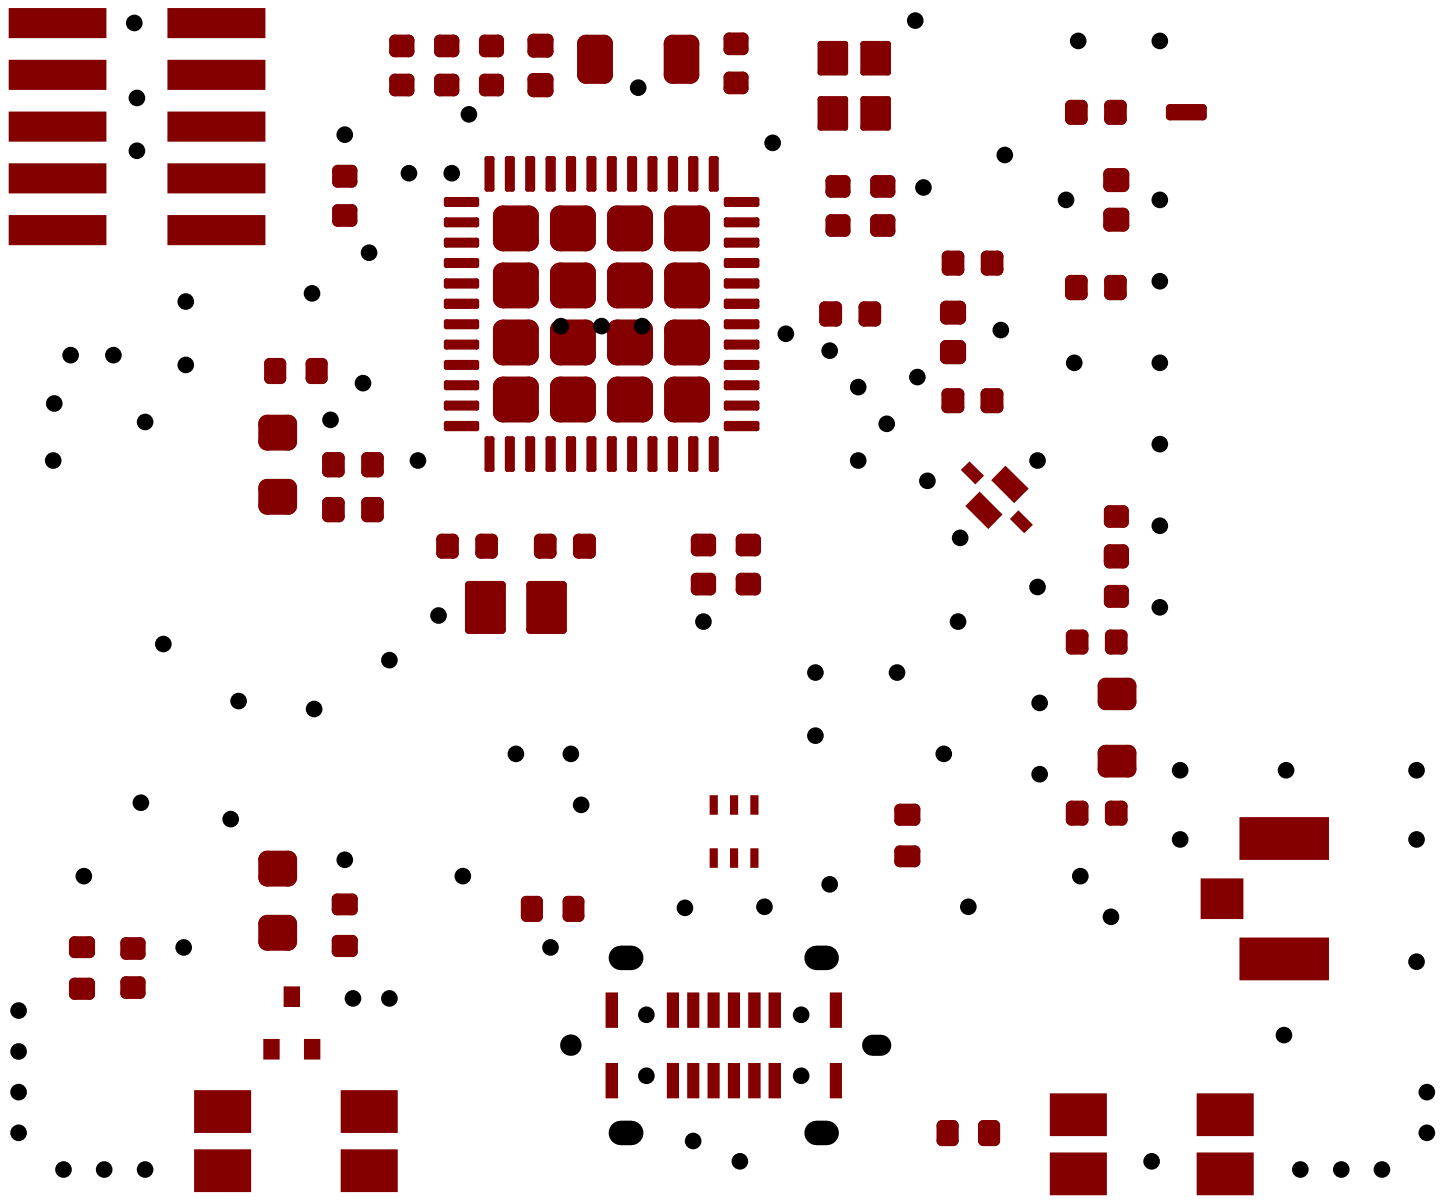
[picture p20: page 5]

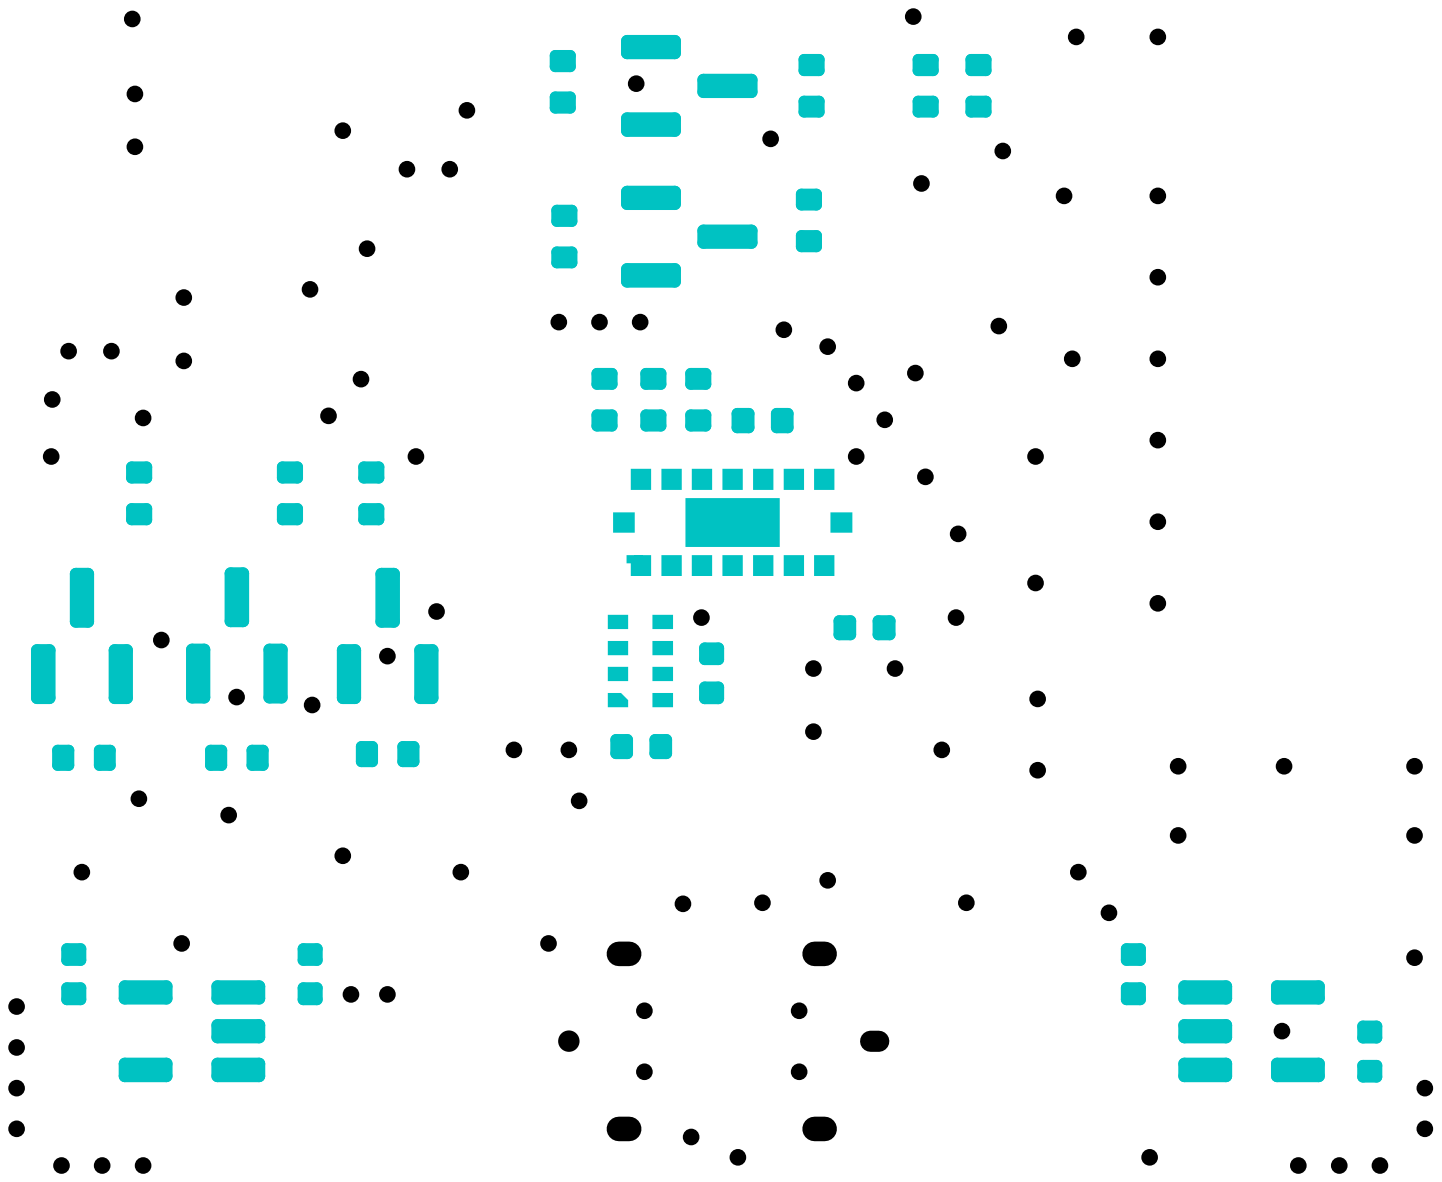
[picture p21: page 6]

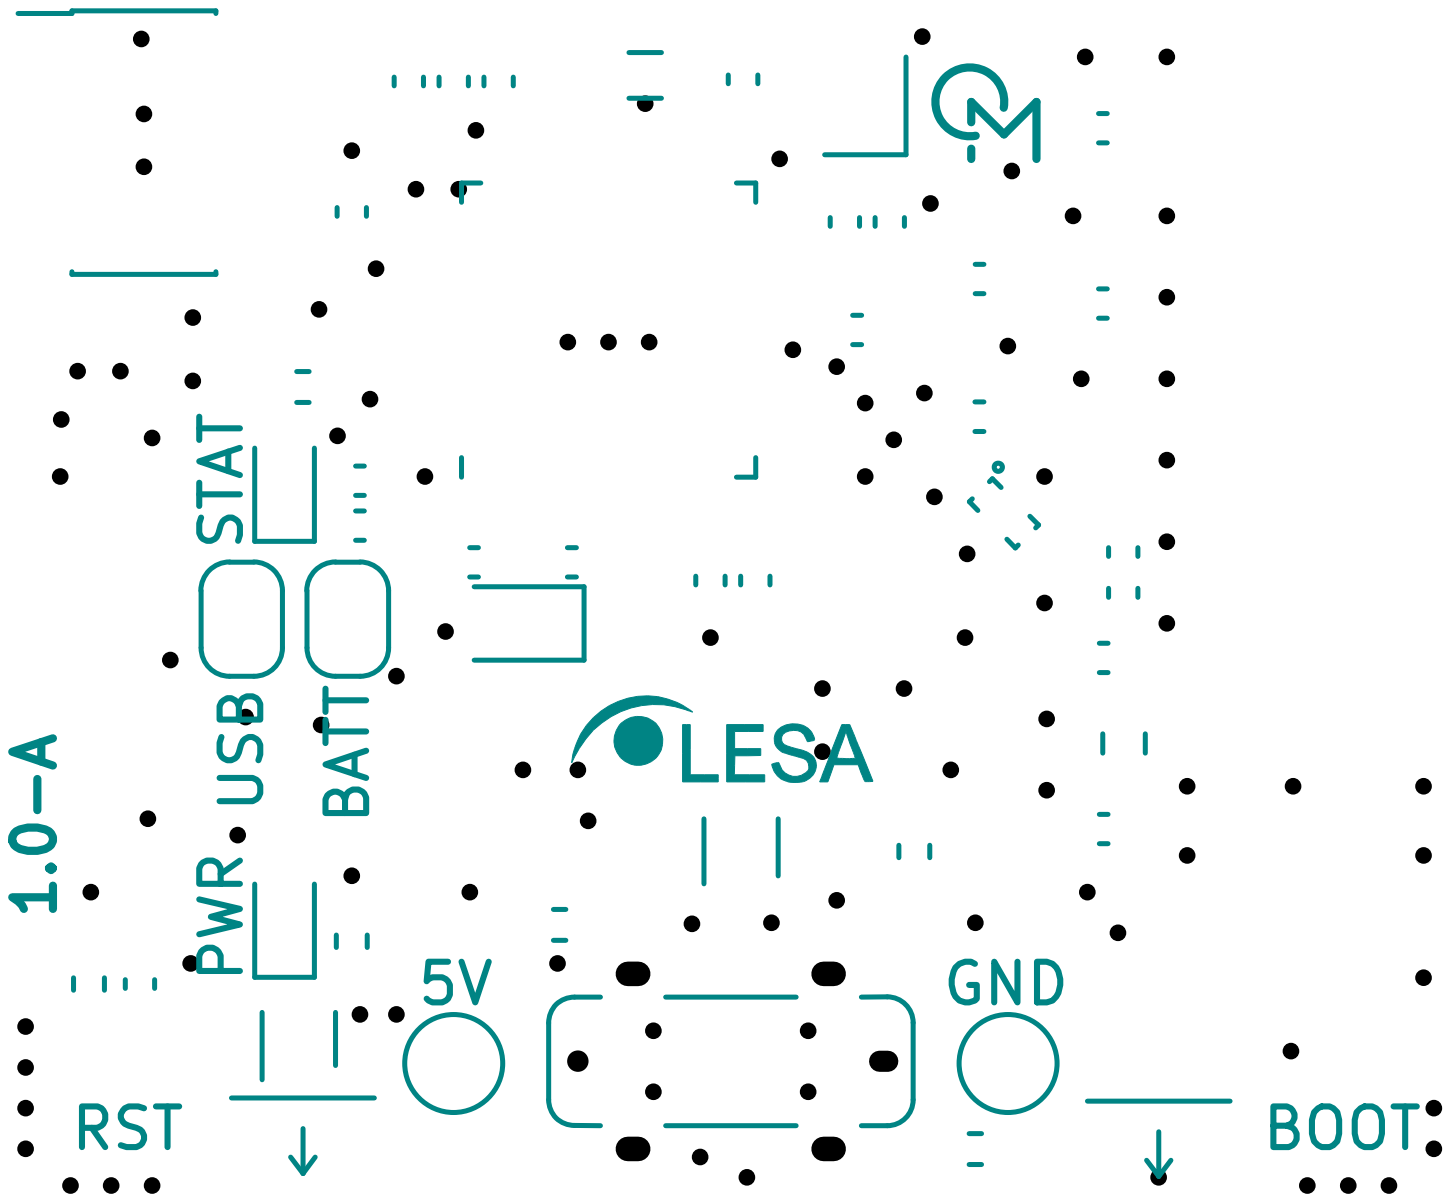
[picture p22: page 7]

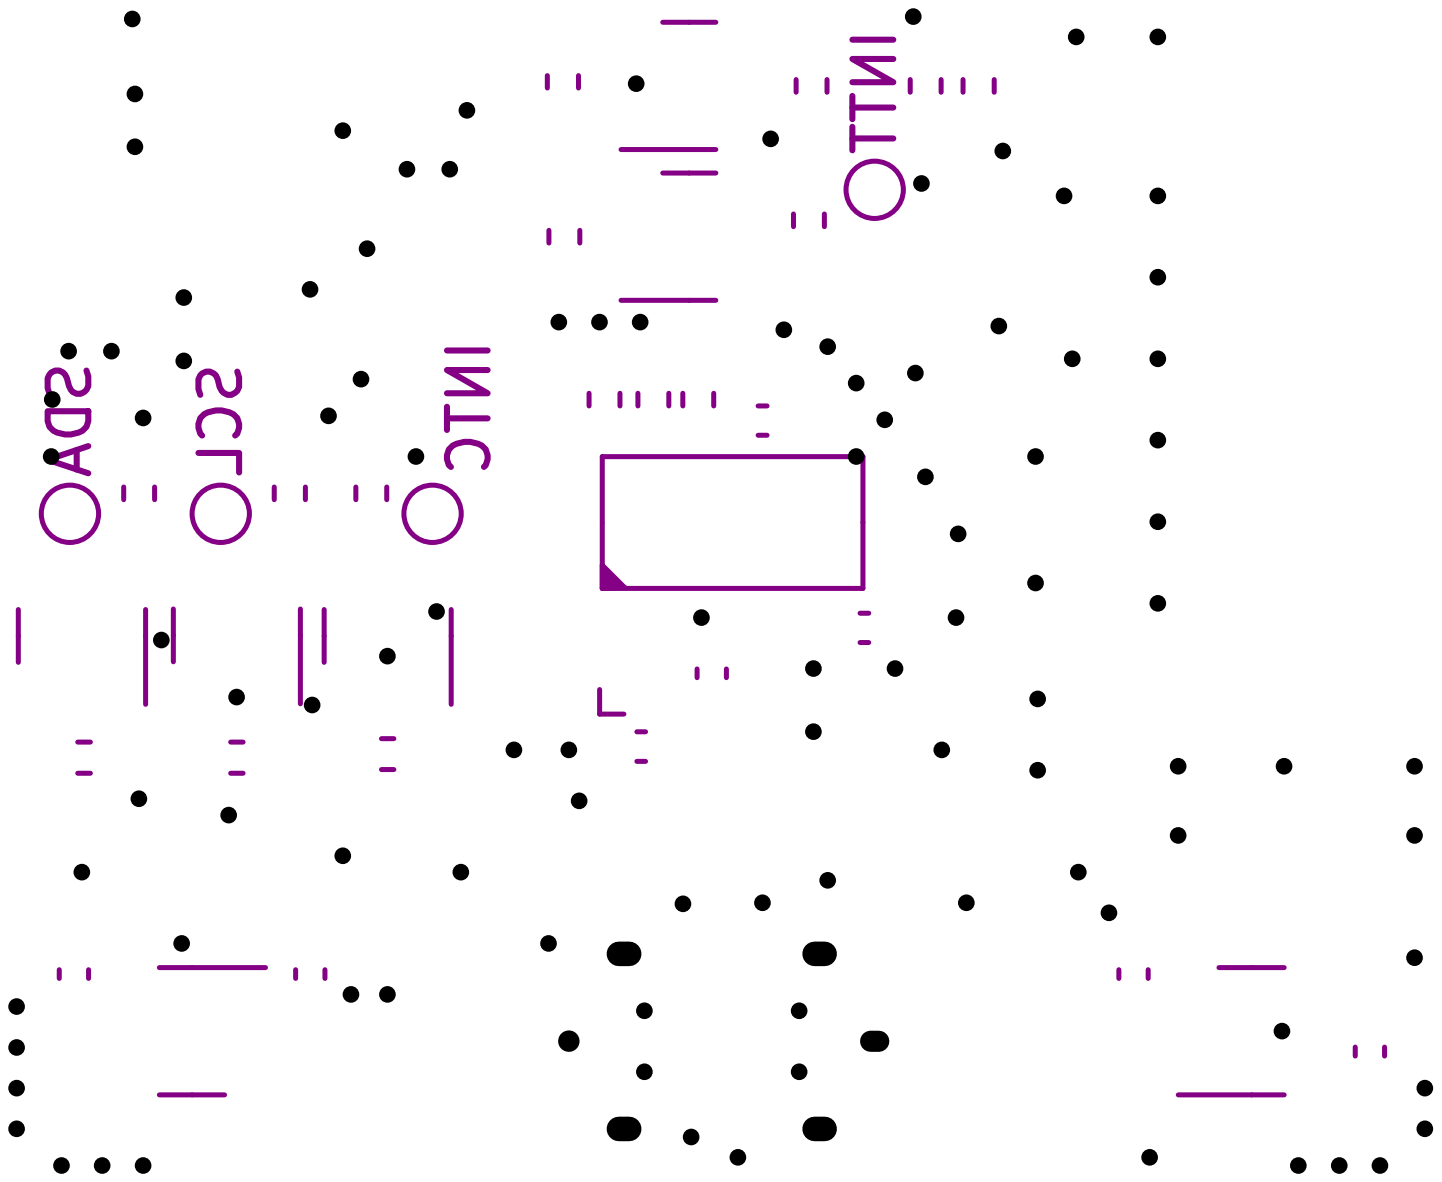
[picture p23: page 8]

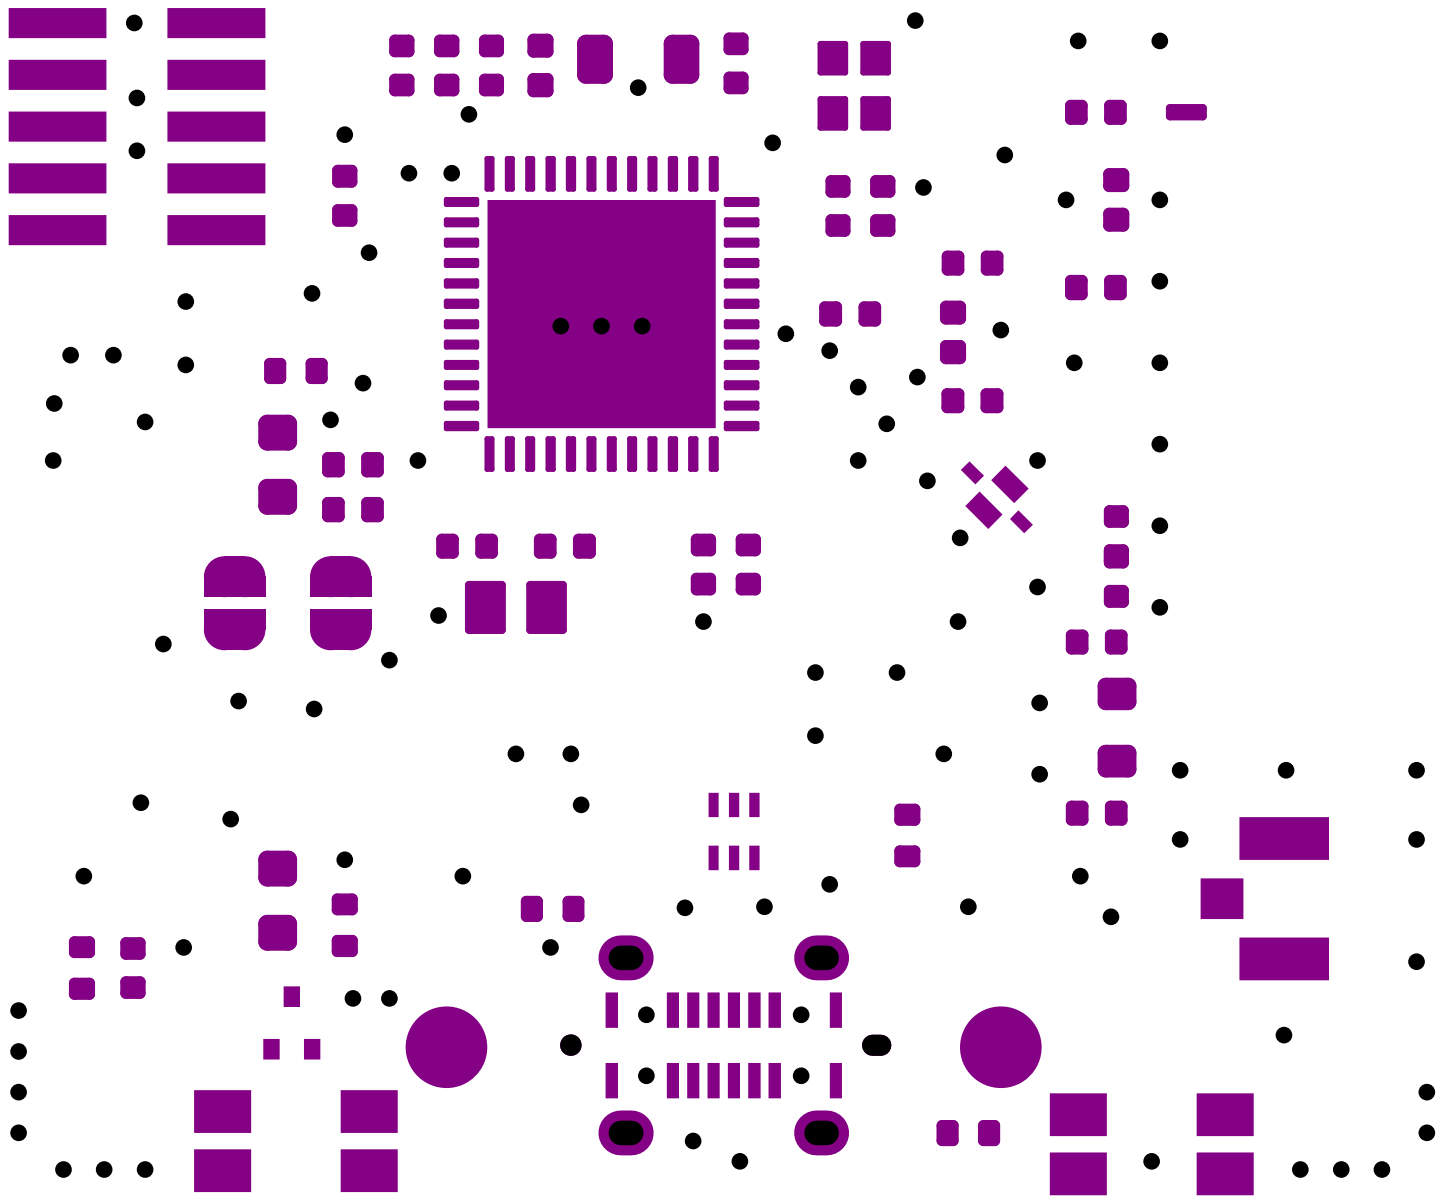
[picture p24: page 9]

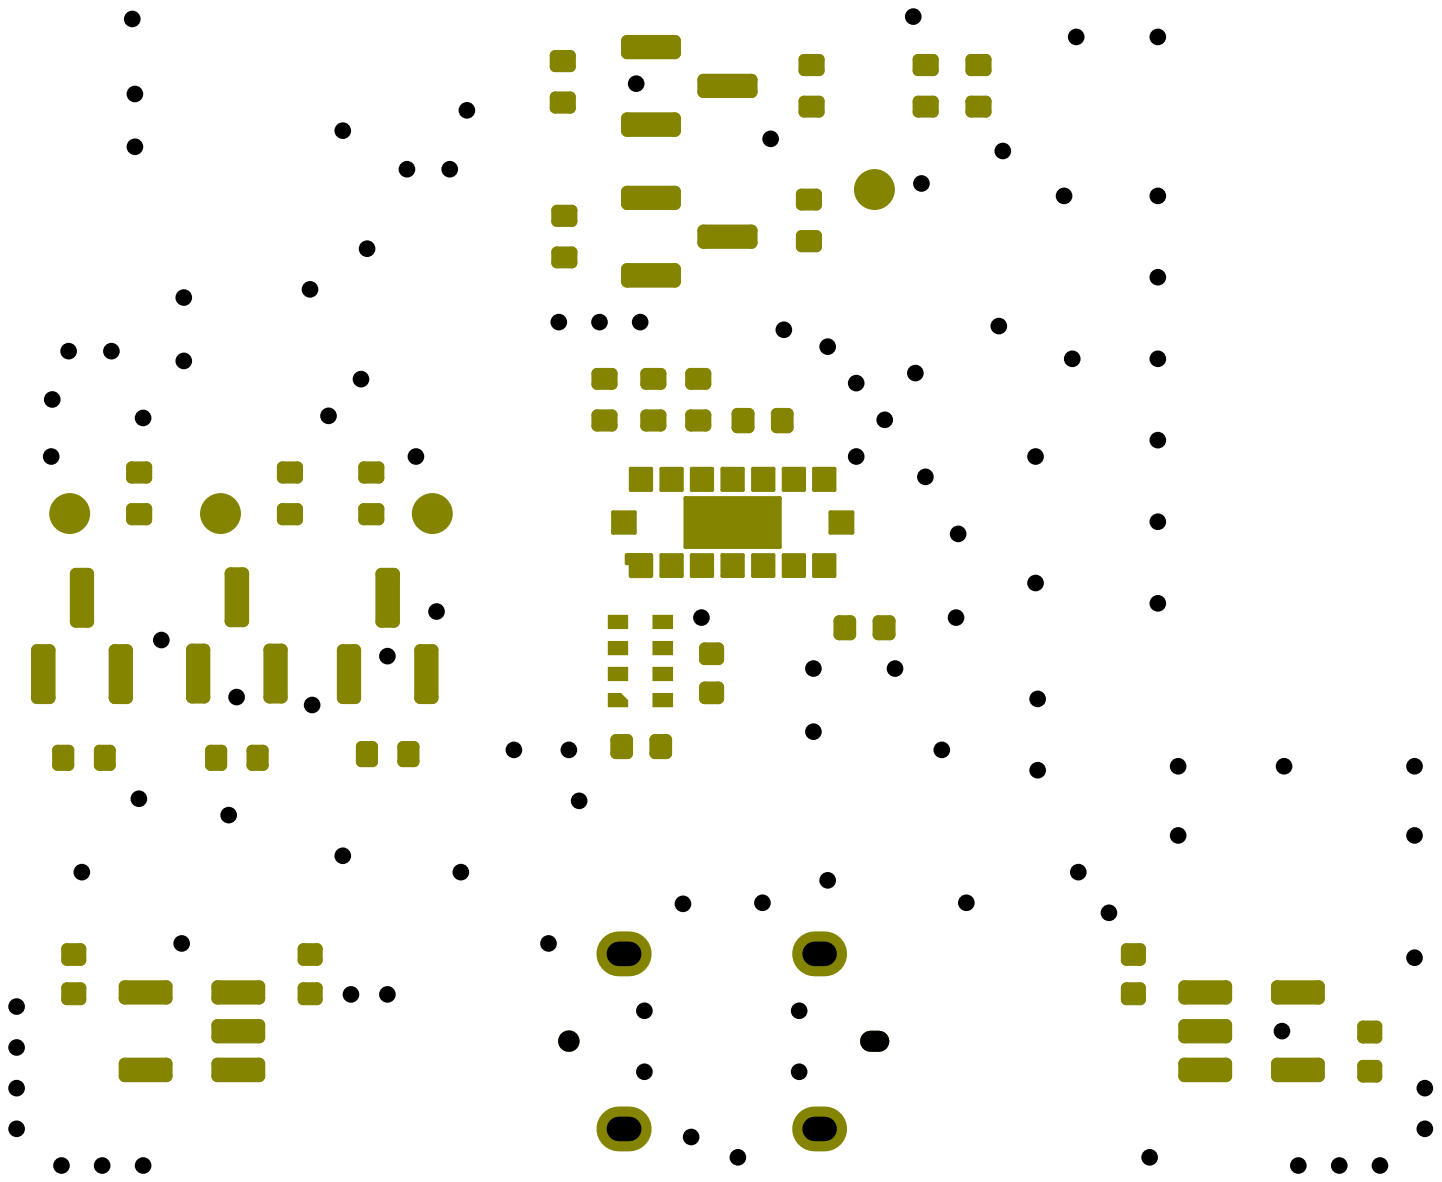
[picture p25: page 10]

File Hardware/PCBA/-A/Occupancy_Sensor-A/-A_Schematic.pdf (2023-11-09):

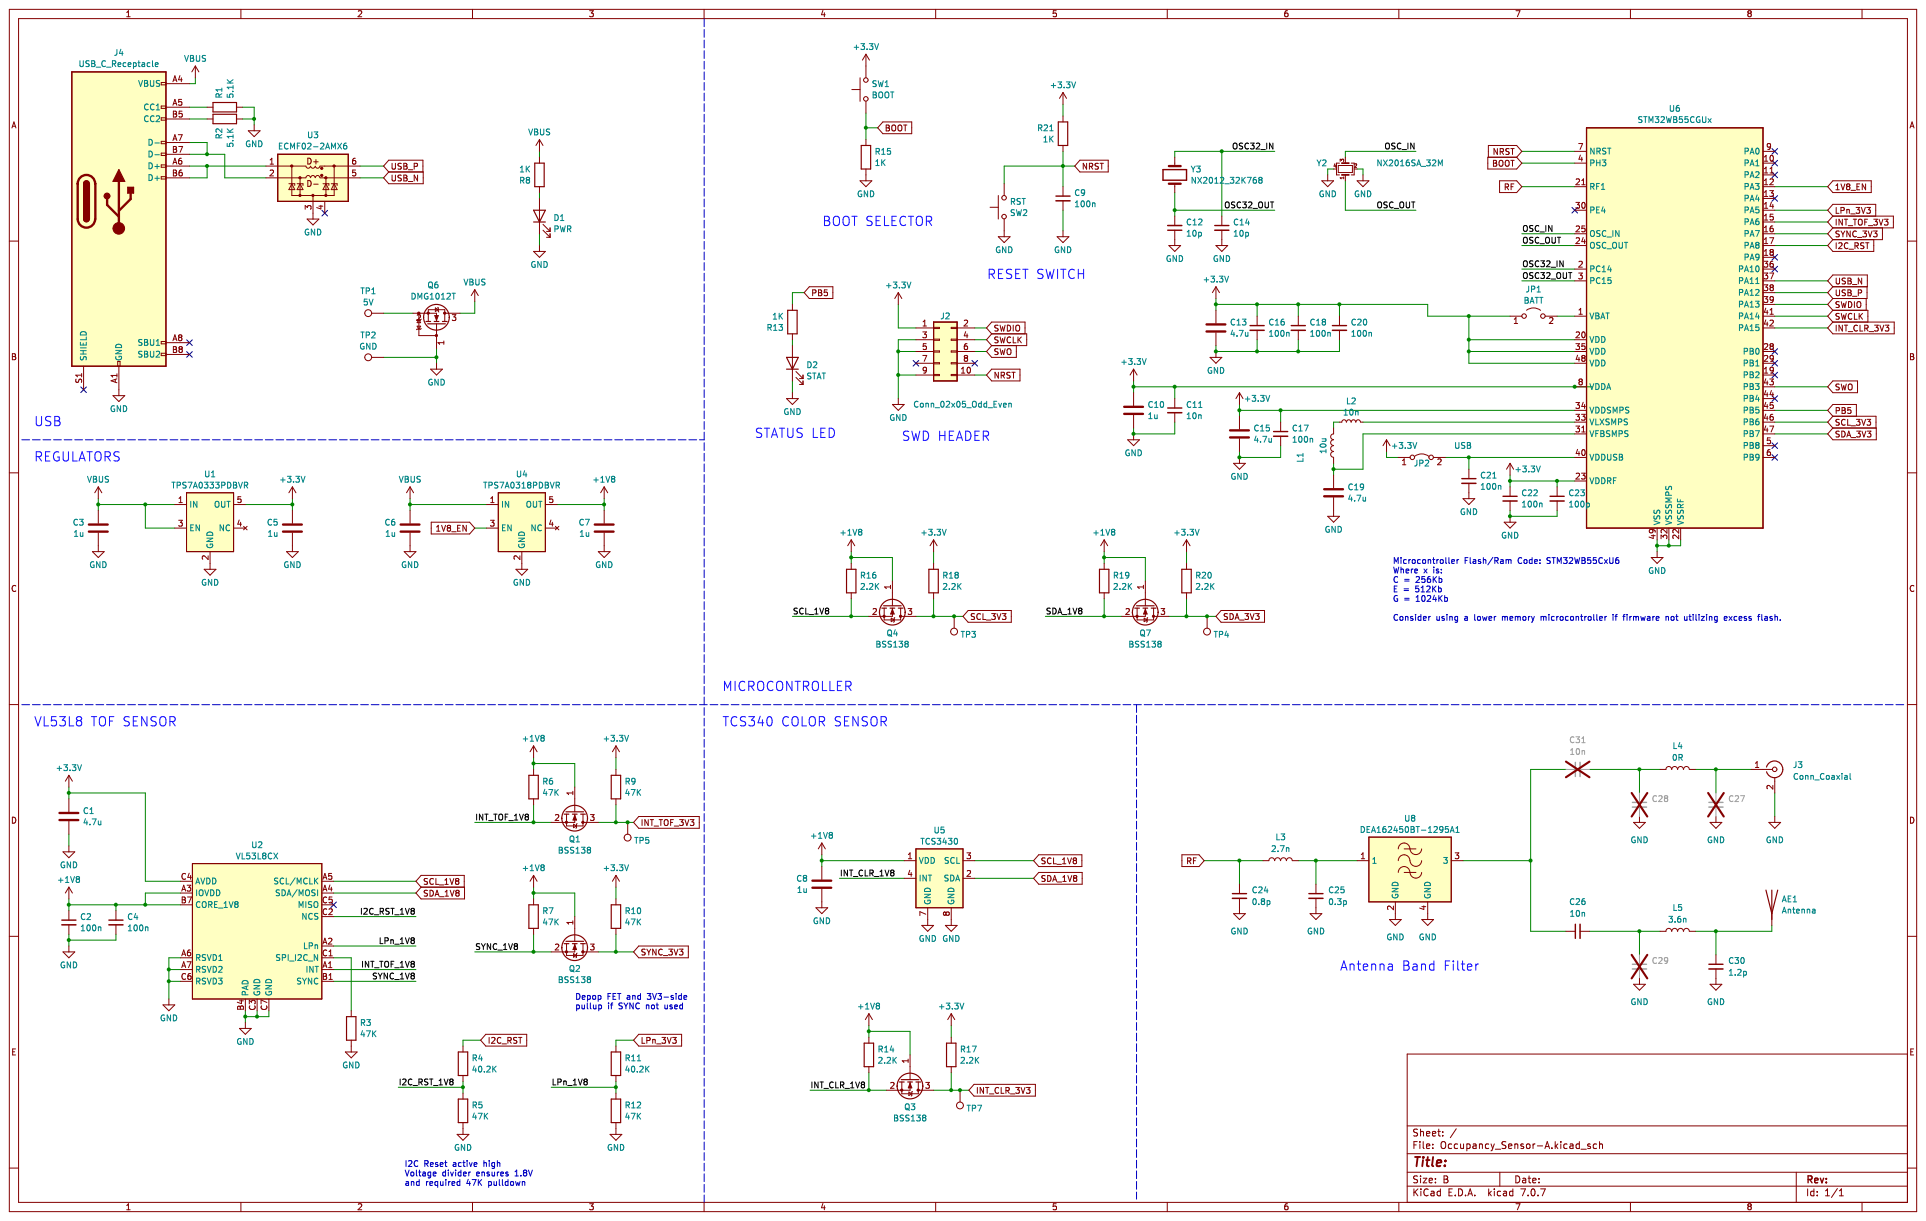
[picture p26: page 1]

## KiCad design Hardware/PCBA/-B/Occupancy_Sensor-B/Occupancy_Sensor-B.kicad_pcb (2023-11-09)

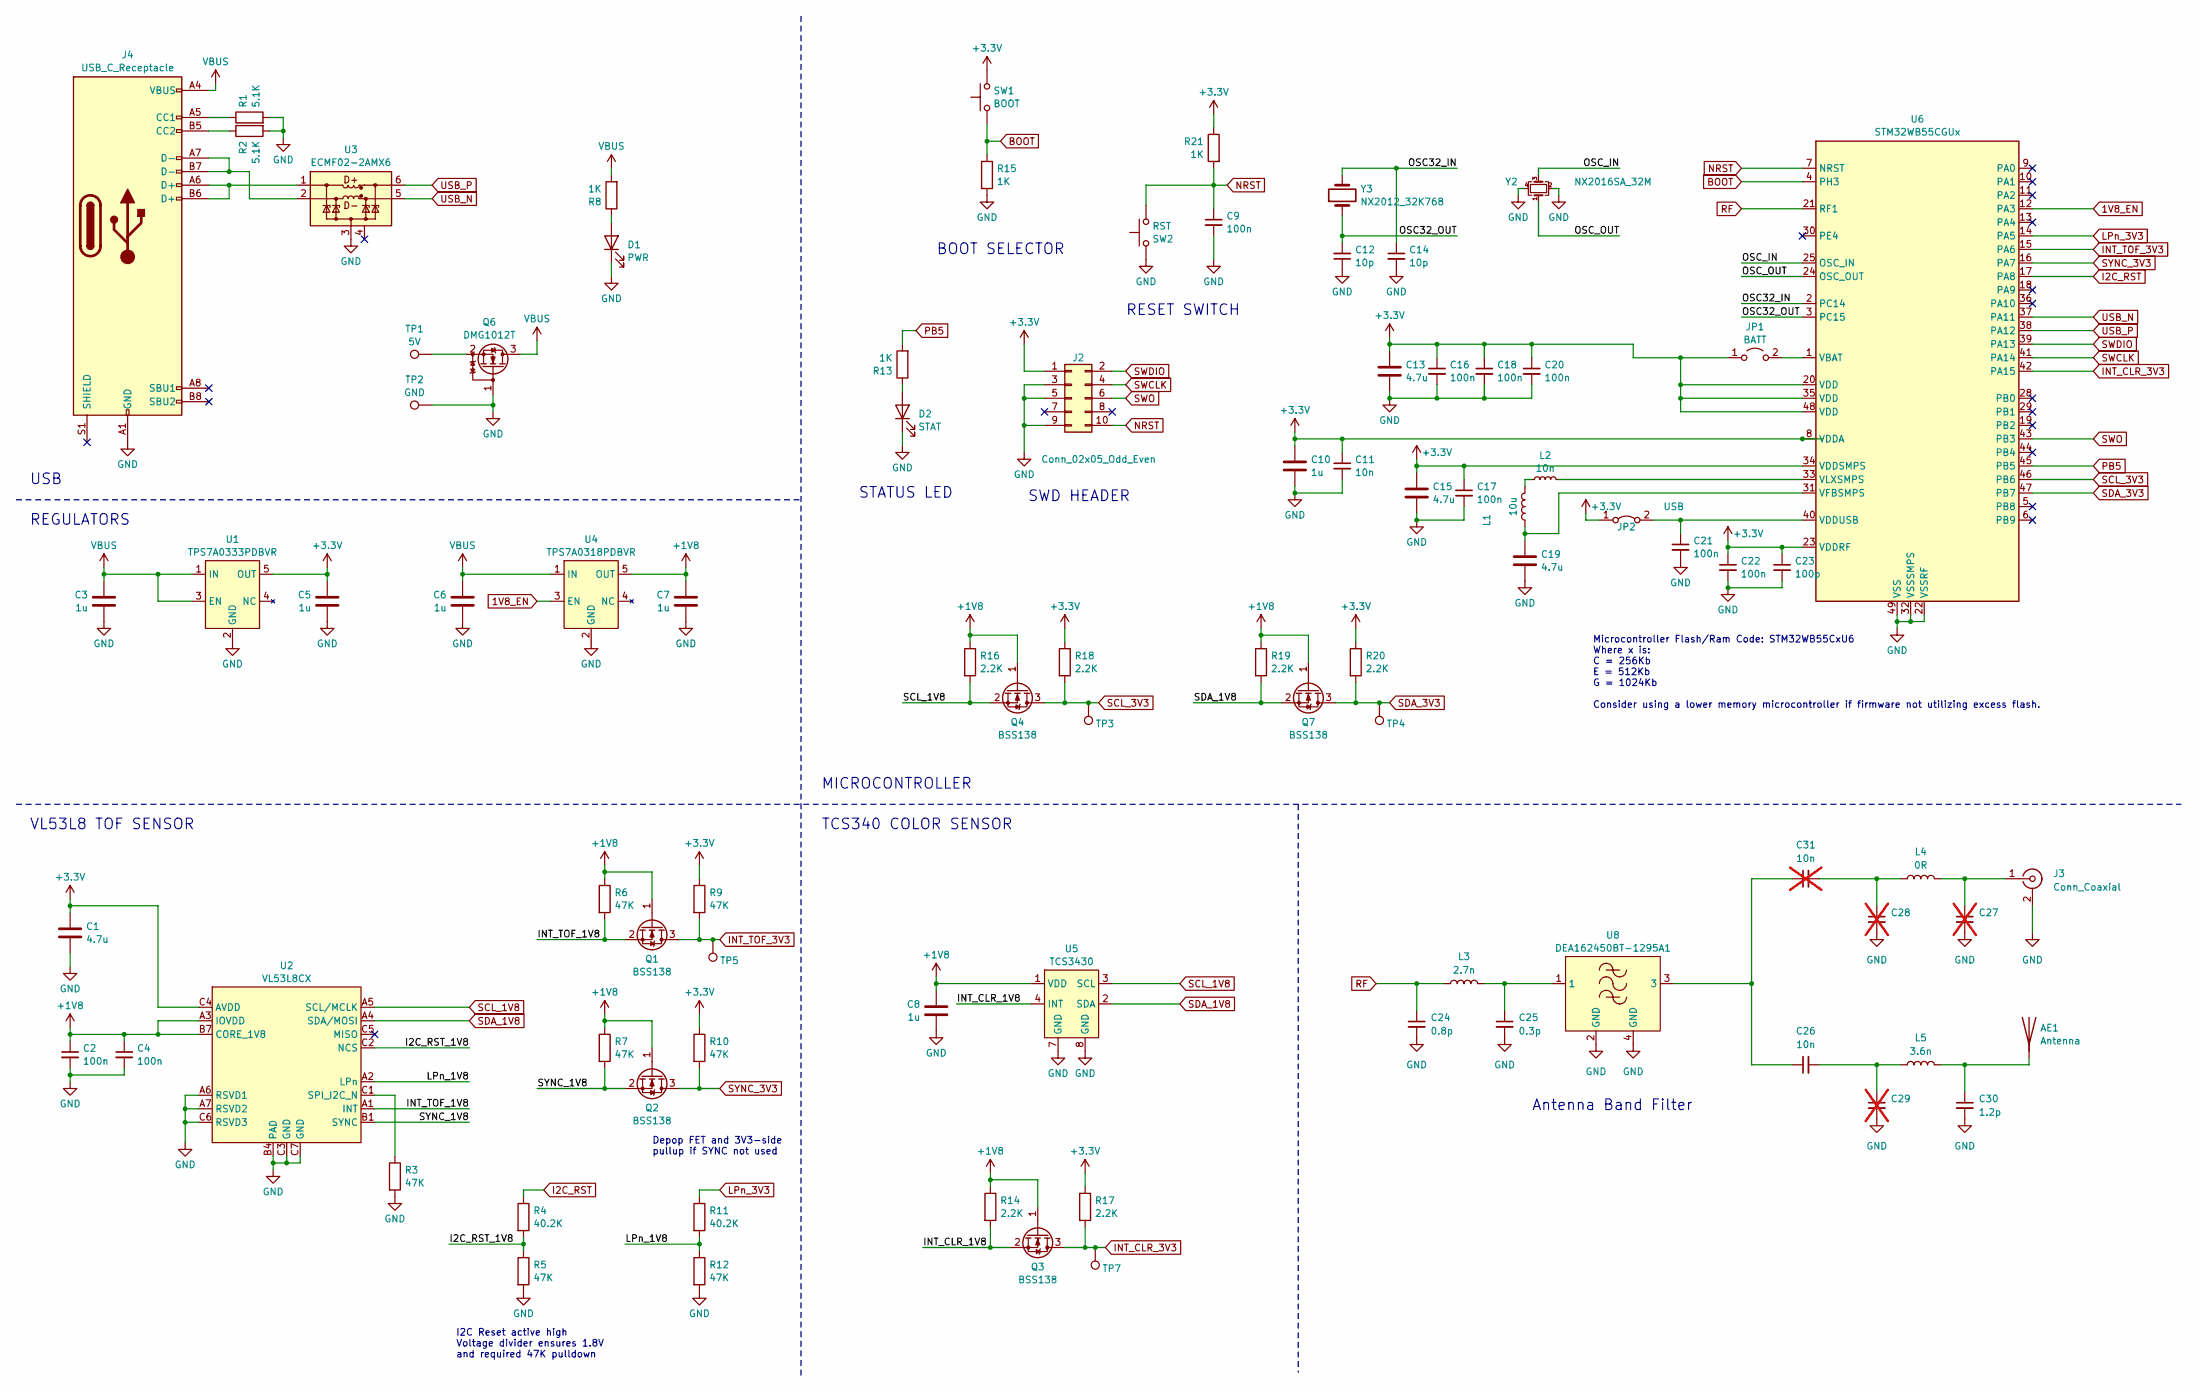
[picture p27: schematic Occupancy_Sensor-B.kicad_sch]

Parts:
AE1: Antenna; AN3359_Meander_Antenna
C1, C13, C15, C19: 4.7u; C_0402_1005Metric; Part # CL05A475MP5NRNC
C2, C4, C9, C16, C17, C18, C20, C21, C22: 100n; C_0402_1005Metric; Part # CL05A104KA5NNNC
C3, C5, C6, C7, C8, C10: 1u; C_0402_1005Metric; Part # CL05A105KP5NNNC
C11, C26: 10n; C_0402_1005Metric; Part # CL05B103KB5NNNC
C12, C14: 10p; C_0402_1005Metric; Part # GRM1555C1H100FA01D
C23: 100p; C_0402_1005Metric; Part # GRM1555C1H101JA01D
C24: 0.8p; C_0402_1005Metric; Part # CC0402BRNPO9BNR80
C25: 0.3p; C_0402_1005Metric; Part # GRM1555C1HR30BA01J
C27, C28, C29: C_0402_1005Metric; not fitted
C30: 1.2p; C_0402_1005Metric; Part # CC0402CRNPO9BN1R2
C31: 10n; C_0402_1005Metric; Part # CL05B103KB5NNNC; not fitted
D1: PWR; LED_0603_1608Metric; Part # LTST-C191KRKT
D2: STAT; LED_0603_1608Metric; Part # LTST-C190GKT
J2: Conn_02x05_Odd_Even; PinHeader_2x05_P1.27mm_Vertical_SMD; Part # 20021121-00010C4LF
J3: Conn_Coaxial; BWU.FL-IPEX1; Part # CONUFL001-SMD-T
J4: USB_C_Receptacle; USB4120-03-C; Part # USB4115-03-C
JP1: BATT; SolderJumper-2_P1.3mm_Open_RoundedPad1.0x1.5mm
JP2: USB; SolderJumper-2_P1.3mm_Bridged_RoundedPad1.0x1.5mm
L1: 10u; L_0805_2012Metric; Part # LQM21FN100M70L
L2: 10n; L_0402_1005Metric; Part # LQG15WZ10NJ02D
L3: 2.7n; L_0402_1005Metric; Part # LQG15HS2N7S02D
L4: 0R; R_0603_1608Metric
L5: 3.6n; L_0402_1005Metric; Part # LQG15HS3N6S02
Q1, Q2, Q3, Q4, Q7: BSS138; SOT-23; Part # BSS138
Q6: DMG1012T; SOT-523; Part # DMG1012T-7
R1, R2: 5.1K; R_0402_1005Metric; Part # ERJ-2RKF5101X
R3, R5, R6, R7, R9, R10, R12: 47K; R_0402_1005Metric; Part # ERJ-2RKF4702X
R4, R11: 40.2K; R_0402_1005Metric; Part # RC0402FR-1340K2L
R8, R13, R15, R21: 1K; R_0402_1005Metric; Part # ERJ-2RKF1001X
R14, R16, R17, R18, R19, R20: 2.2K; R_0402_1005Metric; Part # ERJ-2RKF2201X
SW1: BOOT; EVQ-P7A01P; Part # EVQ-P7A01P
SW2: RST; EVQ-P7A01P; Part # EVQ-P7A01P
TP1: 5V; TestPoint_Pad_D2.0mm
TP2: GND; TestPoint_Pad_D2.0mm
TP3: SCL; TestPoint_Pad_D1.0mm
TP4: SDA; TestPoint_Pad_D1.0mm
TP5: INTT; TestPoint_Pad_D1.0mm
TP7: INTC; TestPoint_Pad_D1.0mm
U1: TPS7A0333PDBVR; SOT-23-5; Part # TPS7A0333PDBVR
U2: VL53L8CX; Part # VL53L8CXV0GC/1
U3: ECMF02-2AMX6; ST_UQFN-6L_1.5x1.7mm_P0.5mm; Part # ECMF02-2AMX6
U4: TPS7A0318PDBVR; SOT-23-5; Part # TPS7A0318PDBVR
U5: TCS3430; Part # TCS34303
U6: STM32WB55CGUx; QFN-48-1EP_7x7mm_P0.5mm_EP5.6x5.6mm; Part # STM32WB55CGU6
U8: DEA162450BT-1295A1; Part # DEA162450BT-1295A1
Y2: NX2016SA_32M; Part # CS06465-32M
Y3: NX2012_32K768; Part # MU00797-32.768K

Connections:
1V8_EN: U4.3 (EN), U6.12 (PA3)
+1V8: C2.1, C4.1, C7.1, C8.1, Q1.1 (G), Q2.1 (G), Q3.1 (G), Q4.1 (G), Q7.1 (G), R6.1, R7.1, R14.1, R16.1, R19.1, U2.A3 (IOVDD), U2.B7 (CORE_1V8), U4.5 (OUT), U5.1 (VDD)
+3.3V: C1.1, C5.1, C10.1, C11.1, C13.1, C15.1, C16.1, C17.1, C18.1, C20.1, C22.1, C23.1, J2.1, JP1.1 (A), JP2.1 (A), R9.1, R10.1, R17.1, R18.1, R20.1, R21.1, SW1.2, U1.5 (OUT), U2.C4 (AVDD), U6.8 (VDDA), U6.20 (VDD), U6.23 (VDDRF), U6.34 (VDDSMPS), U6.35 (VDD), U6.48 (VDD)
/I2C_RST_1V8: R4.2, R5.1, U2.C2 (NCS)
/INT_CLR_1V8: Q3.2 (S), R14.2, U5.4 (INT)
/INT_TOF_1V8: Q1.2 (S), R6.2, U2.A1 (INT)
/LPn_1V8: R11.2, R12.1, U2.A2 (LPn)
/OSC32_IN: C14.1, U6.2 (PC14), Y3.2
/OSC32_OUT: C12.2, U6.3 (PC15), Y3.1
/OSC_IN: U6.25 (OSC_IN), Y2.3
/OSC_OUT: U6.24 (OSC_OUT), Y2.1
/SYNC_1V8: Q2.2 (S), R7.2, U2.B1 (SYNC)
BOOT: R15.1, SW1.1, U6.4 (PH3)
GND: C1.2, C2.2, C3.2, C4.2, C5.2, C6.2, C7.2, C8.2, C9.2, C10.2, C11.2, C12.1, C13.2, C14.2, C15.2, C16.2, C17.2, C18.2, C19.2, C20.2, C21.2, C22.2, C23.2, C24.2, C25.2, C27.2, C28.2, C29.2, C30.2, D1.1 (K), D2.1 (K), J2.3, J2.5, J2.9, J3.2 (Ext), J4.A1 (GND), J4.A12 (GND), J4.B1 (GND), J4.B12 (GND), Q6.1 (G), R1.2, R2.2, R3.2, R5.2, R12.2, R15.2, SW2.2, TP2.1, U1.2 (GND), U2.A6 (RSVD1), U2.A7 (RSVD2), U2.B4 (PAD), U2.C3 (GND), U2.C6 (RSVD3), U2.C7 (GND), U3.3 (GND), U4.2 (GND), U5.7 (GND), U5.8 (GND), U6.22 (VSSRF), U6.32 (VSSSMPS), U6.49 (VSS), U8.2 (GND), U8.4 (GND), Y2.2, Y2.4
I2C_RST: R4.1, U6.17 (PA8)
INT_CLR_3V3: Q3.3 (D), R17.2, TP7.1, U6.42 (PA15)
INT_TOF_3V3: Q1.3 (D), R9.2, TP5.1, U6.15 (PA6)
LPn_3V3: R11.1, U6.14 (PA5)
NRST: C9.1, J2.10, R21.2, SW2.1, U6.7 (NRST)
unnamed: AE1.1 (A), C30.1, L5.2
unnamed: C25.1, L3.2, U8.1
unnamed: C26.1, C31.1, U8.3
unnamed: C26.2, C29.1, L5.1
unnamed: C28.1, C31.2, L4.1
unnamed: D1.2 (A), R8.1
unnamed: D2.2 (A), R13.1
unnamed: C27.1, J3.1 (In), L4.2
unnamed: J4.A5 (CC1), R1.1
unnamed: J4.B5 (CC2), R2.1
unnamed: JP1.2 (B), U6.1 (VBAT)
unnamed: C21.1, JP2.2 (B), U6.40 (VDDUSB)
unnamed: L1.2, L2.1
unnamed: Q6.2 (S), TP1.1
unnamed: R3.1, U2.C1 (SPI_I2C_N)
unnamed: J4.A6 (D+), J4.B6 (D+), U3.1 (D+_in)
unnamed: J4.A7 (D-), J4.B7 (D-), U3.2 (D-_in)
unnamed: C19.1, L1.1, U6.31 (VFBSMPS)
unnamed: L2.2, U6.33 (VLXSMPS)
PB5: R13.2, U6.45 (PB5)
RF: C24.1, L3.1, U6.21 (RF1)
SCL_1V8: Q4.2 (S), R16.2, U2.A5 (SCL/MCLK), U5.3 (SCL)
SCL_3V3: Q4.3 (D), R18.2, TP3.1, U6.46 (PB6)
SDA_1V8: Q7.2 (S), R19.2, U2.A4 (SDA/MOSI), U5.2 (SDA)
SDA_3V3: Q7.3 (D), R20.2, TP4.1, U6.47 (PB7)
SWCLK: J2.4, U6.41 (PA14)
SWDIO: J2.2, U6.39 (PA13)
SWO: J2.6, U6.43 (PB3)
SYNC_3V3: Q2.3 (D), R10.2, U6.16 (PA7)
USB_N: U3.5 (D-_out), U6.37 (PA11)
USB_P: U3.6 (D+_out), U6.38 (PA12)
VBUS: C3.1, C6.1, J4.A4 (VBUS), J4.A9 (VBUS), J4.B4 (VBUS), J4.B9 (VBUS), Q6.3 (D), R8.2, U1.1 (IN), U1.3 (EN), U4.1 (IN)

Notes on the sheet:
USB
STATUS LED
TCS340 COLOR SENSOR
Depop FET and 3V3-side pullup if SYNC not used
VL53L8 TOF SENSOR
BOOT SELECTOR
Microcontroller Flash/Ram Code: STM32WB55CxU6 Where x is: C = 256Kb E = 512Kb G = 1024Kb Consider using a lower memory microcontroller if firmware not utilizing excess flash.
REGULATORS
Antenna Band Filter
SWD HEADER
I2C Reset active high Voltage divider ensures 1.8V and required 47K pulldown
RESET SWITCH
MICROCONTROLLER

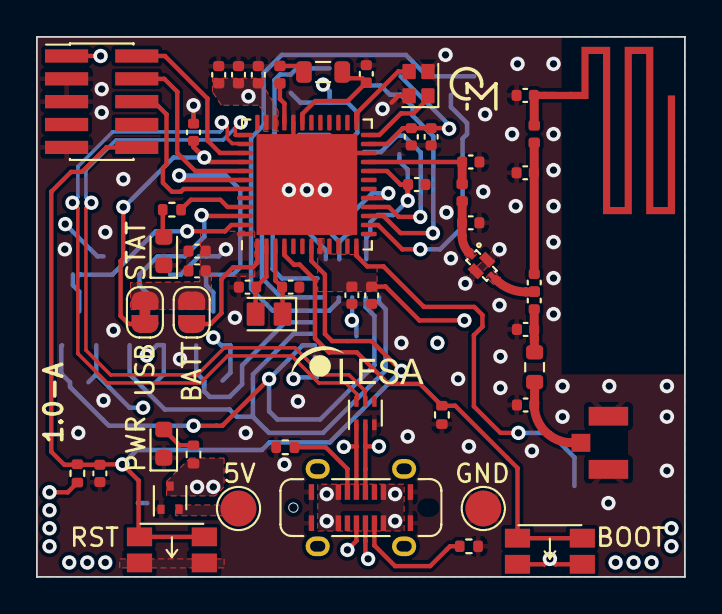
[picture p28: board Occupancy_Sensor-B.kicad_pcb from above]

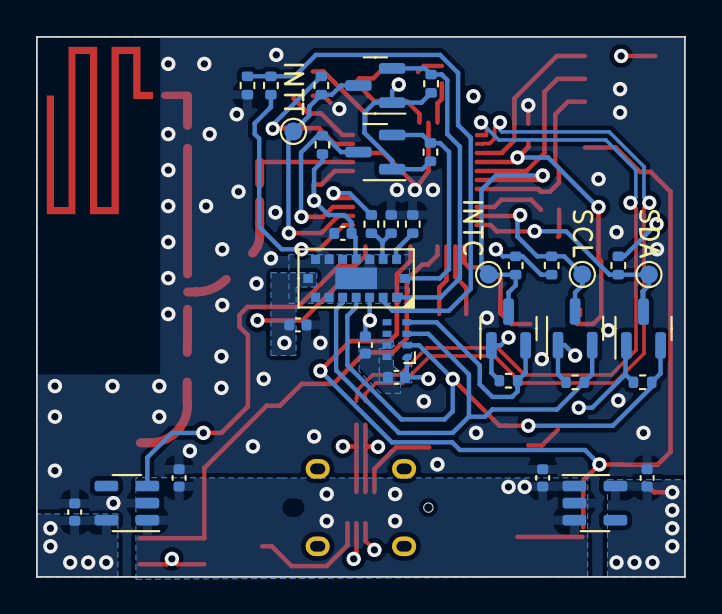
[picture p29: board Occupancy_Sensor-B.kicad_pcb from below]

Board: 4 copper layers, 36.0 x 30.0 mm, 88 parts (36 on the bottom side), 51 nets.

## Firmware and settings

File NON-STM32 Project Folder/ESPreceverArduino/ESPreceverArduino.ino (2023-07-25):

//Watch Dog
#include "soc/timer_group_struct.h"
#include "soc/timer_group_reg.h"
//Wifi
#include <WiFi.h>
#include <WiFiClientSecure.h>
#include <HTTPClient.h>
#include <WiFi.h>
#include "time.h"
#include "sntp.h"
//Others
#include <String.h>
#include <inttypes.h>

////////////////////////Defines//////////////////////////////////////////////////////////////////////////////
// REPLACE with your Domain name and URL path or IP address with path
#define Host_Name "http://mdl-vm11.eng.rpi.edu"
#define Path_Name "/sendToDatabase_Summer.php"
#define Wifi_SSid "NETGEAR"
#define Wifi_password ""
// Time related

const char* NTP_Server1 = "pool.ntp.org";
const char* NTP_Server2 = "time.nist.gov";
const long GMT_Offset_Sec = -14400;
const int DaylightOffset_sec = 3600;
struct timeval tv_now;
struct tm timeinfo;
unsigned long long int time_us;

const char* Time_Zone = "CST6CDT,M3.2.0,M11.1.0";  // TimeZone rule for Europe/Rome including daylight adjustment rules (optional)


#define AckByte 0xFF
////////////////////////Global variables//////////////////////////////////////////////////////////////////////////////
uint8_t data[6 + 128];  //RAW data get from STM32, (low byte + high byte), arranged in this order: XYZ,cell 1,2,3...64
uint8_t AckByteVar;     //Listen for byte 0xFF
HTTPClient http;
SemaphoreHandle_t xDataAvailability = NULL;  //Semaphore Handler
SemaphoreHandle_t WIFISetupFinished = NULL;  //Semaphore Handler

uint64_t chip_id;




/////////////////////////////Functions////////////////////////////////////////////////////////////////////////////////////
void printLocalTime() {
  if (!getLocalTime(&timeinfo)) {
    Serial.println("No time available (yet)");
    return;
  }
  Serial.println(&timeinfo, "%A, %B %d %Y %H:%M:%S");
}
unsigned long getTime() {
  time_t now;
  struct tm timeinfo;
  if (!getLocalTime(&timeinfo)) {
    //Serial.println("Failed to obtain time");
    return (0);
  }
  time(&now);
  return now;
}
// Callback function (get's called when time adjusts via NTP)
void timeavailable(struct timeval* t) {
  Serial.println("Got time adjustment from NTP!");
  printLocalTime();
  xSemaphoreGive(WIFISetupFinished);
}

/////////////////////////////TASKS////////////////////////////////////////////////////////////////////////////////////

void ReadFromUARTTask(void* pt) {
  //this task reads UART
  Serial.print("ReadFromUARTTask created at core: ");
  Serial.println(xPortGetCoreID());
  xSemaphoreTake(xDataAvailability, 50);
  while (1) {
    while (Serial.available()) {
      Serial.readBytes(&AckByteVar, 1);
      if (AckByteVar == 0xFF) {
      } else {
        continue;
      }
      Serial.readBytes(data, 6 + 128);
      xSemaphoreGive(xDataAvailability);
//print data for debug
#if (0)
      Serial.print("DATA:");
      for (int i = 0; i < 67; i++) {
        Serial.printf("%x|", ((uint16_t*)data)[i]);
      }
      Serial.print("\n\r");
#endif
    }

    //watchdog
    TIMERG1.wdt_wprotect = TIMG_WDT_WKEY_VALUE;  // write enable
    TIMERG1.wdt_feed = 1;                        // feed dog
    TIMERG1.wdt_wprotect = 0;                    // write protect
  }
}

void PrintTask(void* pt) {
  while (1) {
  }
}

void WiFiTask(void* pt) {
  Serial.print("WiFiTask created at core: ");
  Serial.println(xPortGetCoreID());

  WiFi.begin(Wifi_SSid, Wifi_password);
  Serial.println("Connecting");

  while (WiFi.status() != WL_CONNECTED) {
    vTaskDelay(25);
    Serial.print(".");
  }
  Serial.print("\nConnected to WiFi network with IP Address: ");
  Serial.println(WiFi.localIP());
  printLocalTime();

  char snum[20];  //string num. only used to convert strings


  while (1) {
    //Check WiFi connection status
    if (WiFi.status() == WL_CONNECTED & xSemaphoreTake(xDataAvailability, 2)) {

      gettimeofday(&tv_now, NULL);
      time_us = (int64_t)tv_now.tv_sec * 1000000L + (int64_t)tv_now.tv_usec;

      //TODO: CHANGE THE FOLLOWING TO SATISFY THE REQUEST//
      //COLOR SENSOR
      String Query_String = "?Color=";
      for (int i = 0; i < 3; i++) {
        Query_String = Query_String + itoa(((uint16_t*)data)[i], snum, 16) + "|";
      }
      Query_String.remove(Query_String.length() - 1);
      //TOF
      Query_String = Query_String + "&ToF=";
      for (int i = 3; i < 67; i++) {
        Query_String = Query_String + itoa(((uint16_t*)data)[i], snum, 16) + "|";
      }
      Query_String.remove(Query_String.length() - 1);
      //TIME STAMP
      gettimeofday(&tv_now, NULL);
      time_us = ((uint64_t)getTime()) * 1000000 + (uint64_t)tv_now.tv_usec;
      char str[256];
      sprintf(str, "%llx", time_us);
      Query_String = Query_String + "&Time_Captured=" + str;
      Serial.println(Query_String);
      /*    gettimeofday(&tv_now,NULL);
    time_us = ((uint64_t)getTime()) * 1000000+ (uint64_t)tv_now.tv_usec;
    char snum[20];//string num. only used to convert strings
    Serial.printf("%lu,--,%llx\n\r",getTime(),time_us);*/
      //MAC
      Query_String = Query_String+"&ESP_Addr="+WiFi.macAddress();


      //http request send
      http.begin(String(Host_Name) + String(Path_Name) + String(Query_String));  //HTTP
      int httpCode = http.GET();
      // httpCode will be negative on error
      if (httpCode == HTTP_CODE_OK) {
        String payload = http.getString();
        Serial.println(payload);
      } else {
        // HTTP header has been send and Server response header has been handled
        Serial.printf("[HTTP] GET... code: %d\n", httpCode);
      }
    }
  }
}

/////////////////////////////SET LOOP TASK////////////////////////////////////////////////////////////////////////////////////

void setup() {
  //semaphore
  xDataAvailability = xSemaphoreCreateBinary();
  WIFISetupFinished = xSemaphoreCreateBinary();
  //default core is 1
  Serial.begin(115200);
  Serial.print("ESP32 Tick Period - ");
  Serial.print(portTICK_PERIOD_MS);
  Serial.println("ms");
  Serial.print("ESP Board MAC Address:  ");
  Serial.println(WiFi.macAddress());
  Serial.print("SETUP LOOP TASK created at core: ");
  Serial.println(xPortGetCoreID());

  sntp_set_time_sync_notification_cb(timeavailable);
  sntp_servermode_dhcp(1);
  configTime(GMT_Offset_Sec, DaylightOffset_sec, NTP_Server1, NTP_Server2);
  configTzTime(Time_Zone, NTP_Server1, NTP_Server2);
  chip_id = ESP.getEfuseMac();
  //task create
  xTaskCreatePinnedToCore(WiFiTask,
                          "PrintTask",
                          1024 * 100,
                          NULL,
                          10,
                          NULL,
                          0);
  xTaskCreatePinnedToCore(ReadFromUARTTask,
                          "ReadFromUARTTask",
                          1024 * 10,
                          NULL,
                          10,
                          NULL,
                          1);
}

void loop() {
}

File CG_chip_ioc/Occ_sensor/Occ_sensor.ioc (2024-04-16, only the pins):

Mcu.UserName=STM32WB55CGUx
PA11.Signal=USB_DM
PA12.Signal=USB_DP
PA13.Signal=SYS_JTMS-SWDIO
PA14.Signal=SYS_JTCK-SWCLK
PA15.GPIO_Label=INT_CLR
PA15.Signal=GPXTI15
PA3.GPIO_Label=LDO_ENABLE
PA3.Signal=GPIO_Output
PA5.GPIO_Label=LPn
PA5.Signal=GPIO_Output
PA6.GPIO_Label=INT_TOF
PA6.Signal=GPXTI6
PA7.GPIO_Label=SYNC_TOF
PA7.Signal=GPIO_Output
PA8.GPIO_Label=I2C_RST_TOF
PA8.Signal=GPIO_Output
PB5.GPIO_Label=LED
PB5.Signal=GPIO_Output
PB6.Signal=I2C1_SCL
PB7.Signal=I2C1_SDA
PC14-OSC32_IN.Signal=RCC_OSC32_IN
PC15-OSC32_OUT.Signal=RCC_OSC32_OUT

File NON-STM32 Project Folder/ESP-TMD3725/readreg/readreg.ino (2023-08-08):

#include "Wire.h"
#include "registers.h"


#define SCL 5
#define SDA 4
#define GPIO1  2
#define LPN 3

typedef struct TMD3725
{
	uint8_t reginfo[35];
	uint8_t colorinfo[9];
}tmd3725;

tmd3725 color_sensor;


void get_reg(uint8_t dev_addr, uint8_t reg_addr, uint8_t *data, size_t len) {
    Wire.beginTransmission(dev_addr);
    Wire.write(reg_addr);
    Wire.endTransmission();
    Wire.requestFrom(dev_addr, len); // We want one byte
    int pointer=0;
    while(len!=0){
      data[pointer] =Wire.read();
      pointer++;
      len--;
    }
}
void set_reg(uint8_t dev_addr, uint8_t reg_addr, uint8_t data) {
    Wire.beginTransmission(dev_addr);
    Wire.write(reg_addr);
    Wire.write(data);
    Wire.endTransmission();
}

uint8_t get_data(uint8_t* reginfo) {

    /*Enable to PILT*/
    get_reg(TMD3725_ADDR, ENABLE_ADDR, reginfo, 9);

    // /*PIHT*/
    get_reg(TMD3725_ADDR, PIHT_ADDR, reginfo+9, 1);

    // /*PERS to PCFG1*/
    get_reg(TMD3725_ADDR, PERS_ADDR, reginfo+10, 4);

    // /*CFG1 to PDATA*/
    get_reg(TMD3725_ADDR, CFG1_ADDR, reginfo+14, 13);

    // /*CFG2*/
    get_reg(TMD3725_ADDR, CFG2_ADDR, reginfo+27, 1);

    // /*CFG3*/
    get_reg(TMD3725_ADDR, CFG3_ADDR, reginfo+28, 1);

    // /*POFFSETL*/
    get_reg(TMD3725_ADDR, POFFSETL_ADDR, reginfo+29, 1);

    // /*POFFSETH*/
    get_reg(TMD3725_ADDR, POFFSETH_ADDR, reginfo+30, 1);

    // /*CALIB*/
    get_reg(TMD3725_ADDR, CALIB_ADDR, reginfo+31, 1);

    // /*CALIBCFG*/
    get_reg(TMD3725_ADDR, CALIBCFG_ADDR, reginfo+32, 1);

    // /*CALIBSTAT*/
    get_reg(TMD3725_ADDR, CALIBSTAT_ADDR, reginfo+33, 1);

    // /*INTENAB*/
    get_reg(TMD3725_ADDR, INTENAB_ADDR, reginfo+34, 1);

    return 0;
}
uint8_t get_optics_data(uint8_t color_array[]) {
    /*
     * FUNCTION: Read from only the color data registers and store the values in array
     * ---------
     * INPUT: color_array[9] - the array used to store data from only the color data registers
     * RETURN: 0 - success
     *         -1 - error
     */

    // TODO ADD ERROR CHECKING
    get_reg(TMD3725_ADDR, CDATAL_ADDR, color_array, 9);
        // if ((color_array[i] = get_reg(TMD3725_ADDR, CDATAL_ADDR+i)) == -1) {
        //     printf("Error happens when reading color value.");
        //     return -1;
        // }

    return 0;
}

void read_ambient(uint8_t* reginfo);


void setup() {
  // put your setup code here, to run once:
  //pinMode(4, INPUT_PULLDOWN);
  //pinMode(5, INPUT_PULLDOWN);
  Wire.begin(4,5,100000);
  Serial.begin(115200);

  get_data(color_sensor.reginfo);

//Find all I2C devices
  int nDevices = 0;
  int address;
  uint error;
  for(address = 1; address < 127; address++ ) 
  {
    // The i2c_scanner uses the return value of
    // the Write.endTransmisstion to see if
    // a device did acknowledge to the address.
    Wire.beginTransmission(address);
    error = Wire.endTransmission();

    if (error == 0)
    {
      Serial.print("I2C device found at address 0x");
      if (address<16) 
        Serial.print("0");
      Serial.print(address,HEX);
      Serial.println("  !");

      nDevices++;
    }
    else if (error==4) 
    {
      Serial.print("Unknown error at address 0x");
      if (address<16) 
        Serial.print("0");
      Serial.println(address,HEX);
    }    
  }
  if (nDevices == 0)
    Serial.println("No I2C devices found\n");
  else
    Serial.println("done\n");
//End find all I2C devices

//print regs
  int iteration = 0;
  while(iteration<35) {
    Serial.print("Element ");
    Serial.print(iteration);
    Serial.print(": ");
    Serial.println(color_sensor.reginfo[iteration]);
    iteration++;
  }
  //finish print regs
//init sensor
  set_reg(TMD3725_ADDR,ENABLE_ADDR,0b00000011);//enable sensor
  set_reg(TMD3725_ADDR,CFG1_ADDR,0b00000011);  //set A gain 64
  set_reg(TMD3725_ADDR,WTIME_ADDR,0b11111111);  //set A gain 64



}
//

void loop() {

  neopixelWrite(RGB_BUILTIN,1,0,0); // Red
  delay(100);
  neopixelWrite(RGB_BUILTIN,0,1,0); // Green
  delay(100);
  neopixelWrite(RGB_BUILTIN,0,0,1); // Blue
  delay(100);

  read_ambient(color_sensor.reginfo);

}

void read_ambient(uint8_t* reginfo){
  get_data(reginfo);
  /*
#define CDATAL_ADDR     0x94	// R      18
#define CDATAH_ADDR     0x95	// R      19
#define RDATAL_ADDR     0x96	// R      20
#define RDATAH_ADDR     0x97	// R      21
#define GDATAL_ADDR     0x98	// R      22
#define GDATAH_ADDR     0x99	// R      23
#define BDATAL_ADDR     0x9A	// R      24
#define BDATAH_ADDR     0x9B	// R      25*/
/*
  uint16_t clearreg=reginfo[18]|(reginfo[19]<<8);
  uint16_t redreg=reginfo[20]|(reginfo[21]<<8);
  uint16_t greenreg=reginfo[22]|(reginfo[23]<<8);
  uint16_t bluereg=reginfo[24]|(reginfo[25]<<8);*/
  uint16_t clearreg=reginfo[19];
  uint16_t redreg=reginfo[21];
  uint16_t greenreg=reginfo[23];
  uint16_t bluereg=reginfo[25];
  Serial.printf("Clear: %u\tRed: %u\tGreen: %u\tBlue: %u\n",clearreg,redreg,greenreg,bluereg);
}

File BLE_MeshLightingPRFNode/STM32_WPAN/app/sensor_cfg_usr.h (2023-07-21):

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

/* Define to prevent recursive inclusion -------------------------------------*/
#ifndef SENSOR_USR_CFG_H
#define SENSOR_USR_CFG_H

/**
* Maximum count of settings that can be supported by a sensor
* E.g., 5 sensors 
*  1st sensor has 2 settings
*  2nd sensor has 3 settings
*  3rd sensor has 2 settings
*  4th sensor has 1 setting
*  5th sensor has 2 settings
*  This value is max(2, 3, 2, 1, 2) = 3
*  value is >=1 
*/
#define SENSOR_MAX_SETTINGS_COUNT                                           2

/**
* Maximum count of series column that is supported by a sensor
* E.g., 2 sensors supporting series column
*  One sensor supports 2 columns while other sensor supports 20 columns
*  This value is max(2, 20) = 20
*  value is >=1
*/
#define SENSOR_MAX_SERIES_COUNT                                            2

/** 
* Total sensors count on all elements
* It is sum of sensors count on all elements
* Sensor init fails in case of mismatch with sensor server initialization parameters
*/
#define TOTAL_SENSORS_COUNT                                                 2

/** 
* Sum of sensor settings on all sensors on all elements
* Sensor init fails in case of mismatch with sensor server initialization parameters
*/
#define TOTAL_SENSOR_SETTINGS_COUNT                                         4

/** 
* Sum of sensor series columns on all sensors on all elements
* Sensor init fails in case of mismatch with sensor server initialization parameters
*/
#define TOTAL_SENSOR_SERIES_COLUMN_COUNT                                   0


/**
* This structure contains sensor setting initialization parameters
*/ 
typedef struct
{
    uint16_t settingPropertyId;
    uint8_t settingAccess;
    uint32_t settingRaw;
}sensor_settings_init_params_t;


/**
* This structure contains sensor series column initialization parameters
*/ 
typedef struct
{
    uint32_t rawX;
    uint32_t columnWidth;
}sensor_series_column_init_params_t;


/**
* This structure contains sensor initialization parameters
*/ 
typedef struct
{
    uint8_t elementIdx;
    uint16_t propertyId;
    uint16_t positiveTolerance;
    uint16_t negativeTolerance;
    uint8_t samplingFunction;
    uint8_t measurementPeriod;
    uint8_t updateInterval;
    uint8_t dataLength;
    uint8_t cadenceState;
    uint32_t valuesRange;
    uint8_t settingsCount;
    sensor_settings_init_params_t settings[SENSOR_MAX_SETTINGS_COUNT];
    uint16_t seriesCount;
    sensor_series_column_init_params_t seriesColumn[SENSOR_MAX_SERIES_COUNT];
}sensor_init_params_t;


/**
* This structure contains sensor server initialization parameters
*/ 
typedef struct
{
    uint8_t sensorsCount;
    sensor_init_params_t sensorInitParams[TOTAL_SENSORS_COUNT];
} sensor_server_init_params_t;


/**
* Below section represents initialization parameters of sensors supported
* Define sensors in ascending order of element index followed by ascending 
* order of Property IDs else initialization of sensor structure would fail
* Single element can support one instance of sensor PID, there can't be multiple
* instances of same PID on same element 
* For e.g. 10 sensors with PID (PID1 < PIDn ... < PID7) supported on 3 elements
* with element index (0, 1 and 2) in below fashion
* Element index 0 supports sensors corresponding to PID3, PID4, PID6 and PID7
* Element index 1 supports sensors corresponding to PID2, PID4, PID5 and PID6
* Element index 2 supports sensors corresponding to PID1, PID5
* Corrector order of naming sensors (SENSORX) is
* Element index 0 -> SENSOR1(PID3), SENSOR2(PID4), SENSOR3(PID6) and SENSOR4(PID7)
* Element index 1 -> SENSOR5(PID2), SENSOR6(PID4), SENSOR7(PID5), and SENSOR8(PID6)
* Element index 2 -> SENSOR9(PID1), and SENSOR10(PID5)
*/

/* Sensor 1 initialization */

/**
* Element index for SENSOR1
* varies from 0 to n-1 (n = number of elements)
*/
#define SENSOR1_ELEMENT_IDX                                                  0

/**
* Property ID of sensor, identifies device characteristics and other features
* Defined by Mesh Device Properties or a custom value
* 16 bit value
* 0x0000 - Prohibited
*/
#define SENSOR1_PROPERTY_ID                    INITIAL_CIE_1931_CHROMATICITY_COORDINATES_PID
#define SENSOR1_POSITIVE_TOLERANCE             SENSOR_POSITIVE_TOLERANCE_UNSPECIFIED
#define SENSOR1_NEGATIVE_TOLERANCE             SENSOR_NEGATIVE_TOLERANCE_UNSPECIFIED
#define SENSOR1_SAMPLING_FUNCTION              SENSOR_SAMPLING_FUNC_UNSPECIFIED
#define SENSOR1_MEASUREMENT_PERIOD             SENSOR_MEASUREMENT_PERIOD_NA
#define SENSOR1_UPDATE_INTERVAL                SENSOR_UPDATE_INTERVAL_NA
#define SENSOR1_DATA_LENGTH                    8
#define SENSOR1_CADENCE_STATE                  SENSOR_CADENCE_NOT_SUPPORTED
#define SENSOR1_VALUES_RANGE                   0
#define SENSOR1_SETTINGS_COUNT                 2
#define SENSOR1_SETTING1_PROPERTY_ID           0x00BB
#define SENSOR1_SETTING1_ACCESS                SENSOR_SETTING_ACCESS_READ
#define SENSOR1_SETTING1_RAW                   0
#define SENSOR1_SETTING2_PROPERTY_ID           0x00AD
#define SENSOR1_SETTING2_ACCESS                SENSOR_SETTING_ACCESS_READ_WRITE
#define SENSOR1_SETTING2_RAW                   0
#define SENSOR1_SERIES_COUNT                   0

#define SENSOR1_SETTINGS1_INIT_PARAMS \
{\
  SENSOR1_SETTING1_PROPERTY_ID,\
  SENSOR1_SETTING1_ACCESS,\
  SENSOR1_SETTING1_RAW \
}

#define SENSOR1_SETTINGS2_INIT_PARAMS \
{\
  SENSOR1_SETTING2_PROPERTY_ID,\
  SENSOR1_SETTING2_ACCESS,\
  SENSOR1_SETTING2_RAW \
}

#define SENSOR1_INIT_PARAMS \
{\
  SENSOR1_ELEMENT_IDX,\
  SENSOR1_PROPERTY_ID,\
  SENSOR1_POSITIVE_TOLERANCE,\
  SENSOR1_NEGATIVE_TOLERANCE,\
  SENSOR1_SAMPLING_FUNCTION,\
  SENSOR1_MEASUREMENT_PERIOD,\
  SENSOR1_UPDATE_INTERVAL,\
  SENSOR1_DATA_LENGTH,\
  SENSOR1_CADENCE_STATE,\
  SENSOR1_VALUES_RANGE,\
  SENSOR1_SETTINGS_COUNT,\
  {\
      SENSOR1_SETTINGS1_INIT_PARAMS,\
      SENSOR1_SETTINGS2_INIT_PARAMS\
  },\
  SENSOR1_SERIES_COUNT,\
  {\
    {0}\
  }\
}
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

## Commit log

2023-07-26 Revert "Merge branch 'main' of https://github.com/IAmiku/BLE_MeshLightingPRFNode"
    This reverts commit cc6e01be3f71f41e9e0ab04cfcfdd12129b0051d, reversing
    changes made to 3f9a2da5abd98b4a43d3730e0c2ac256727dd4f4.
    [ESPreceverArduino.ino]
2023-07-26 Revert "stm folder"
    This reverts commit 3f9a2da5abd98b4a43d3730e0c2ac256727dd4f4.
    [TMD3725.h, app_conf.h, app_entry.c]
2023-07-26 Identify non stm32 project related documents
2023-08-08 update php files
    [partitions.csv]
2023-08-08 Removed Occupancy_Integration
    [partitions.csv]
2023-08-11 Shrinks the interrupt range
2023-09-25 Add PCBA KiCad project
    [Occupancy_Sensor-A.kicad_pcb, Occupancy_Sensor-A.kicad_sch]
2023-10-02 Add 5V-3V3 DCDC, USB, RESET
    [Occupancy_Sensor-A.kicad_sch, color_sensor.kicad_sch]
2023-10-04 Start layout, component fixes
    [Occupancy_Sensor-A.kicad_pcb, Occupancy_Sensor-A.kicad_sch]
2023-10-04 Add central custom parts directory
    [Occupancy_Sensor-A.kicad_sch]
2023-10-04 Adding Antenna Design & Band Pass Filter
    Adding LFB182G45CGFD436 into schematic lib
    Adding Antenna Design Schematic Diagram
    [Antenna.kicad_sch, Occupancy_Sensor-A.kicad_sch]
2023-10-04 General layout, regulator fixes
    [Occupancy_Sensor-A.kicad_pcb, Occupancy_Sensor-A.kicad_sch]
2023-10-11 Add regulators, TOF, color sensor footprints
    [color_sensor.kicad_sch]
2023-10-11 Add kicad-specific gitignore
2023-10-12 Add TOF footprint, component to schematic
    [Antenna.kicad_sch, Occupancy_Sensor-A.kicad_pcb, Occupancy_Sensor-A.kicad_sch]
2023-10-12 Update antenna circuit
    [Antenna.kicad_sch, Occupancy_Sensor-A.kicad_sch]
2023-10-16 General layout, footprint fixes
    [Occupancy_Sensor-A.kicad_pcb, Occupancy_Sensor-A.kicad_sch]
2023-10-18 Layout, power planes, prelim antenna placement
    [Occupancy_Sensor-A.kicad_pcb, Occupancy_Sensor-A.kicad_sch]
2023-10-18 Finalize IO pinout, layout
    [Occupancy_Sensor-A.kicad_pcb, Occupancy_Sensor-A.kicad_sch]
2023-10-20 Layout cleanup, silk fixes
    [Occupancy_Sensor-A.kicad_pcb, Occupancy_Sensor-A.kicad_sch]
2023-10-22 Adding footprint to the LFB182G45CGFD436
    Adding PCB footprint to the LFB182G45CGFD436
2023-10-23 Add Exclusion Zone Models
    Add rough models with accurate exclusion zones for TCS3430 and VL53L8CX
    [TCS3430_exclusion_r1.STEP, VL53L8CX_exclusion_r1.STEP]
2023-10-23 Adding coaxial connector
    Adding coaxial connector.
    Remove On board PCB antenna.
    [Antenna.kicad_sch, TCS3430_exclusion_r1.STEP, VL53L8CX_exclusion_r1.STEP]
2023-11-01 Layout fixes, boot selector, testpoints
    [Occupancy_Sensor-A.kicad_pcb, Occupancy_Sensor-A.kicad_sch]
2023-11-02 Update exclusion geometries
    Change TCS3430 height to match VL53L8, change each zone to be a different color
    [TCS3430_exclusion_r1.STEP, TCS3430_exclusion_r2.STEP, VL53L8CX_exclusion_r1.STEP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]
2023-11-02 RF layout
    [Occupancy_Sensor-A.kicad_pcb, Occupancy_Sensor-A.kicad_sch]
2023-11-06 IPEX socket PCB trace change
    Changed the through hole path of the LFB182G45CGFD436 and reroute the PCB trace of the IPEX socket.
    [Occupancy_Sensor-A.kicad_pcb]
2023-11-08 Final TOF sensor layout
    [Occupancy_Sensor-A.kicad_pcb, Occupancy_Sensor-A.kicad_sch]
2023-11-09 Add Gerbers, PnP, BOM, PDFs for -A rev
    [Occupancy_Sensor-A-B_Cu.gbr, Occupancy_Sensor-A-B_Mask.gbr, Occupancy_Sensor-A-B_Paste.gbr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]
2023-12-13 Upload enclosure design files
    [Occupancy_Assy-A.SLDASM, Occupancy_Sensor-A.SLDPRT, Occupancy_Sensor_Case_Bottom-A.SLDPRT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]
2024-03-26 Update pin assignment for ToF sensor firmware
    [Antenna.kicad_sch, Occupancy_Sensor-B.kicad_pcb, Occupancy_Sensor-B.kicad_sch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]
2024-04-16 Complete Pin Assignment for Custom PCB
2024-04-19 Adding BSP driver and some dependent
2024-04-22 Added the Drivers and related files
    Still need works to be done with reroute the I2C init functions. But most of the main files are there.

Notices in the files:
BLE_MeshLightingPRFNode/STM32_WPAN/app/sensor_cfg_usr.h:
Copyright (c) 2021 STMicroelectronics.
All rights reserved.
